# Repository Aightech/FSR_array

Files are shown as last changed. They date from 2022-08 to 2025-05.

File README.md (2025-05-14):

# FSR_array

This project implements a electronic skin using a FSR accelerometers arrays. 

The electronic board uses two multiplexers and two 16-channel ADCs to read the FSRs. The multiplexers are used to select the row or column of the FSRs array. The ADCs are used to read the FSRs values.
A teensy 4.1 is used to control the multiplexers and ADCs and to send the data to the computer.
The teensy 4.1 is connected to the computer using a USB cable or ethernet cable.
There are two modes of operation:
- **Single mode**: In this mode, you can connect a FSR array with up to 32x32 FSRs.
- **Dual mode**: In this mode, you can connect two FSR arrays with up to 16x16 FSRs each.

The sampling is around 400KHz/channel. So for a 16x16 FSR array, the sampling rate is around 400KHz/256 = 1562.5Hz.

The project contains a C++/matlab/python code demonstrating how to communicate with the teensy 4.1 and read the FSRs values.

### Submodules dependencies
#### libraries
- [built_lsl](lib/built_lsl/README.md)
- [com_client](lib/com_client/README.md)

# Building source code

To build the project run:
```bash
cd FSR_array
mkdir build && cd build
cmake .. && make
```

# Demonstration app

When the project have been built, you can run:
```bash
./FSR_array -h
```
to get the demonstration app usage.

# Example
Open the main.cpp file to get an example how to use the lib.

# Contributing
See [CONTRIBUTING.md](CONTRIBUTING.md) for details on our code of conduct, and the process for submitting pull requests to us.

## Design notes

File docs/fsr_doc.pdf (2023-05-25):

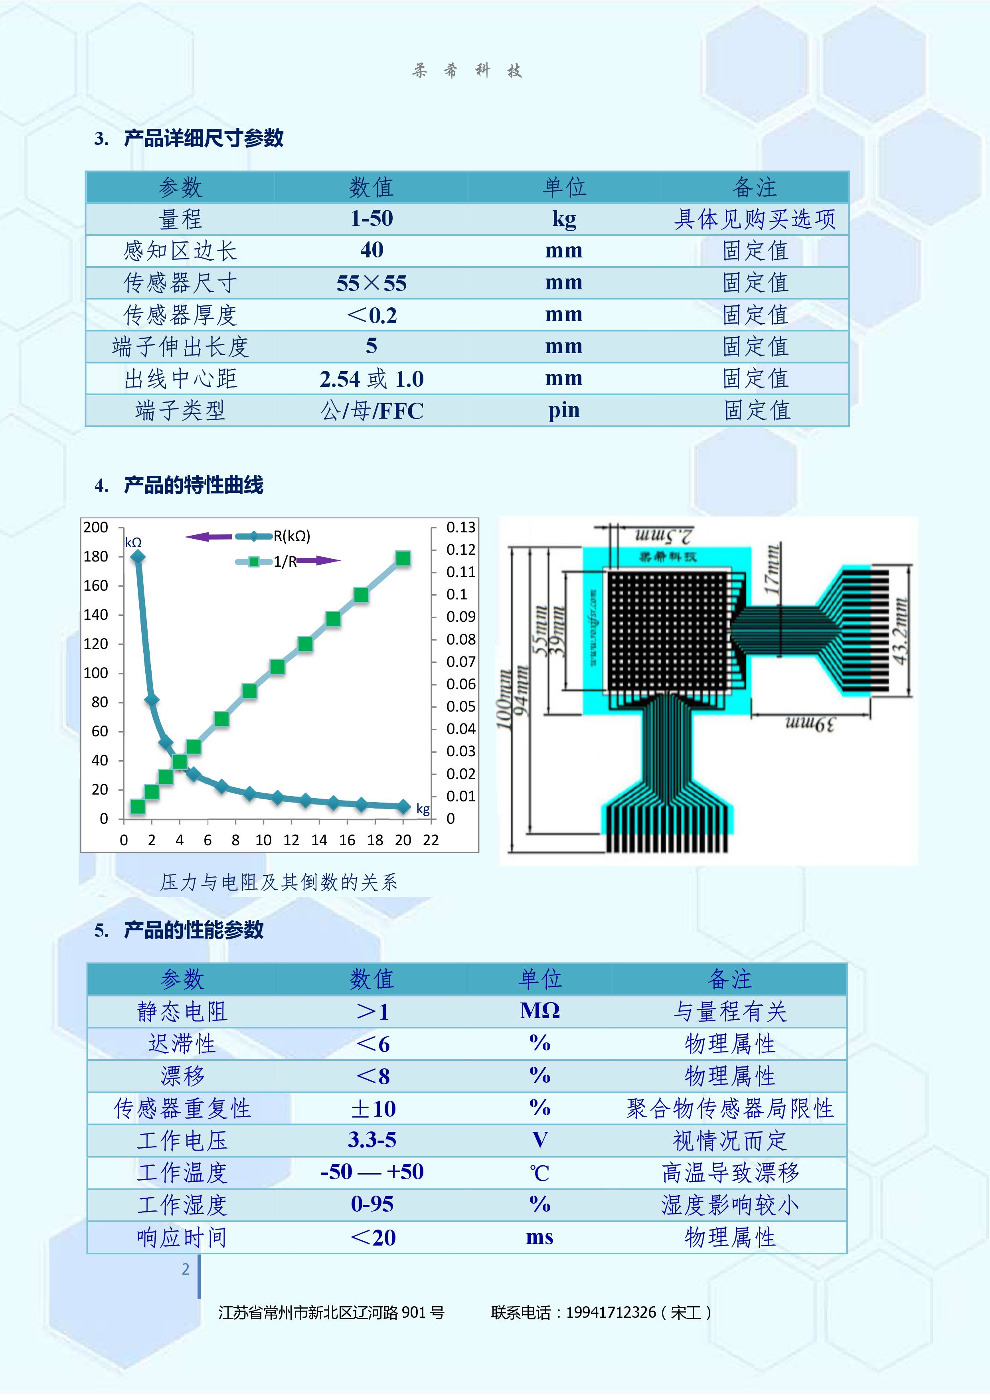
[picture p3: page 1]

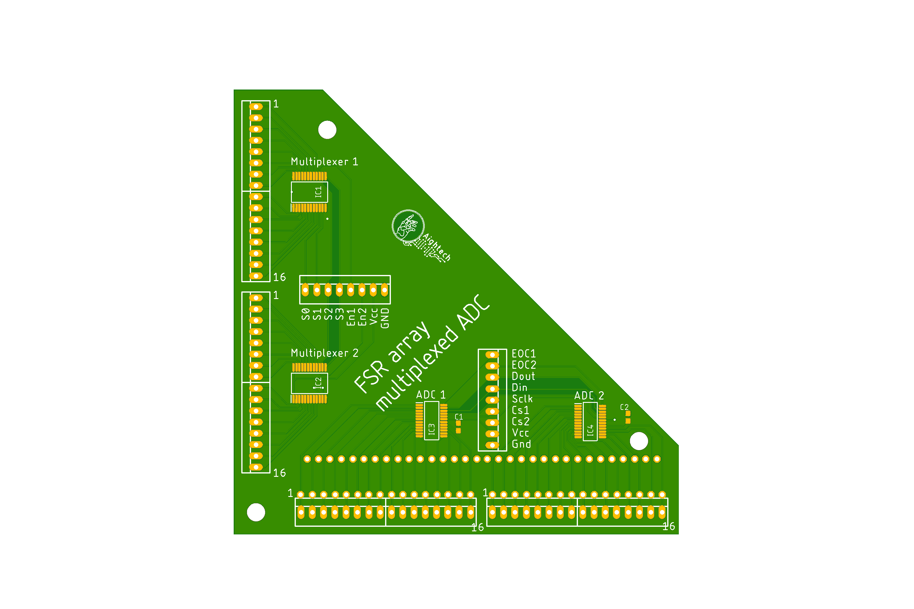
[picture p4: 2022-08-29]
docs/TOP.png

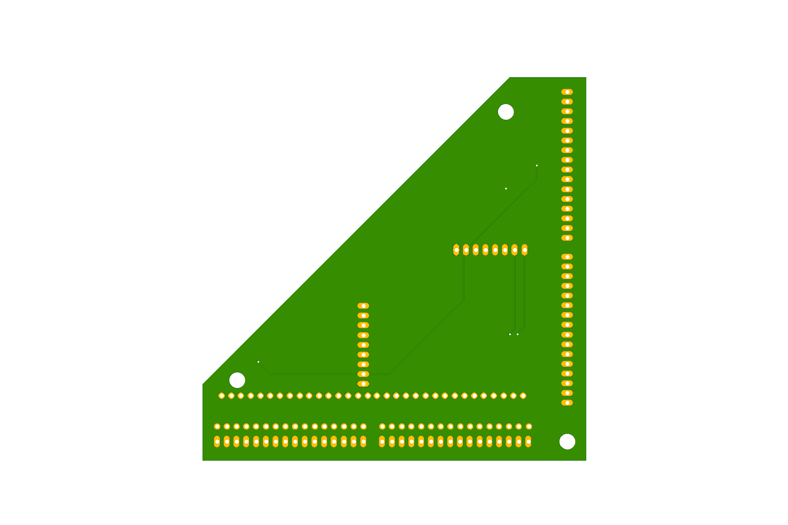
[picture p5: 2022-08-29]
docs/BOT.png

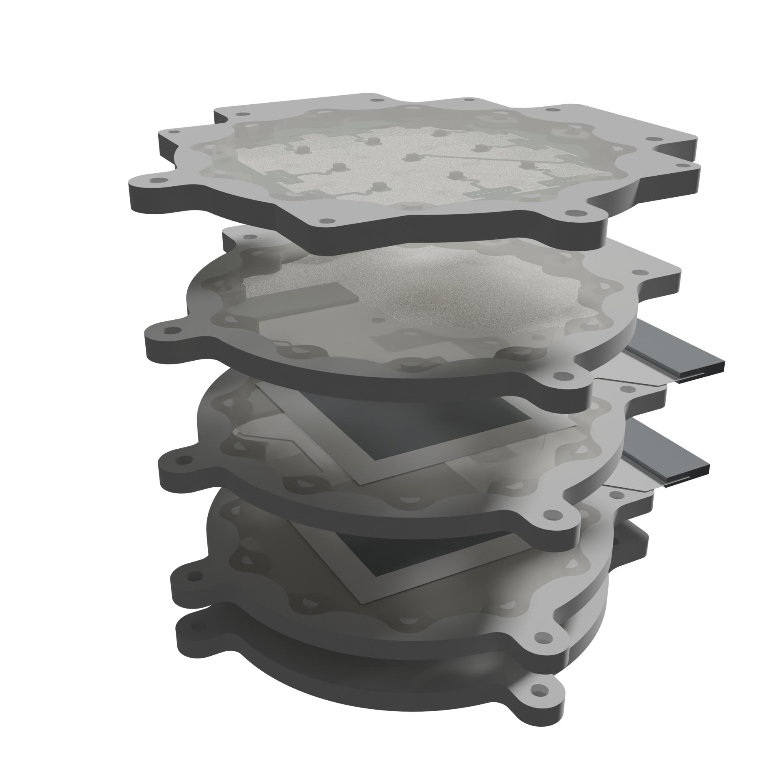
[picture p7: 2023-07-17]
models/blender/eSkin.png

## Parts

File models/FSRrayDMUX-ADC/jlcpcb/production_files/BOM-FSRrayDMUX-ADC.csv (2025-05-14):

Comment | Designator | Footprint | LCSC | Quantity
FPC-05F-16PH20 | FPC1,FPC2 | FPC-SMD_16P-P0.50_FPC-05F-16PH20 | C2856801 | 2
Conn_01x06_Pin | J1 | PinSocket_1x06_P2.54mm_Vertical |  | 1
CD74HC4067SM | MUX1 | SSOP-24_5.3x8.2mm_P0.65mm |  | 1
Conn_01x06_Pin | J4 | PinSocket_1x06_P2.54mm_Vertical |  | 1
R_Pack04 | RN4 | R_Array_Convex_4x0402 |  | 1
R_Pack04 | RN2 | R_Array_Convex_4x0402 |  | 1
R_Pack04 | RN1 | R_Array_Convex_4x0402 |  | 1
100n | C1 | C_0402_1005Metric |  | 1
R_Pack04 | RN3 | R_Array_Convex_4x0402 |  | 1
MAX11632EEGT | ADC1 | MAX11632EEGT |  | 1

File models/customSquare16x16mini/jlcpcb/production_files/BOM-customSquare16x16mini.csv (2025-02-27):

Comment | Designator | Footprint | LCSC | Quantity
FPC-05F-16PH20 | FPC1,FPC2 | FPC-SMD_16P-P0.50_FPC-05F-16PH20 | C2856801 | 2
Conn_01x16_Pin | J1 | PinSocket_1x16_P2.54mm_Vertical |  | 1
Conn_01x16_Pin | J2 | PinSocket_1x16_P2.54mm_Vertical |  | 1

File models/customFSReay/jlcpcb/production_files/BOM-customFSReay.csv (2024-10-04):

Comment | Designator | Footprint | LCSC
AFC01-S12FCA-00 | FPC1 | FPC-SMD_AFC01-S12FCA-00 | C262661
R_Pack04 | RN1 | R_Array_Convex_4x0402
R_Pack04 | RN4 | R_Array_Convex_4x0402
100n | C1 | C0603
R_Pack04 | RN2 | R_Array_Convex_4x0402
R_Pack04 | RN3 | R_Array_Convex_4x0402
CD74HC4067SM | MUX1 | SSOP-24_5.3x8.2mm_P0.65mm
MAX11632EEGT | ADC1 | MAX11632EEGT

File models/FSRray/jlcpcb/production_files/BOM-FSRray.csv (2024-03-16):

Comment | Designator | Footprint | LCSC
R_Pack04 | RN5 | R_Array_Convex_4x0402
MountingHole | H5 | MountingHole_3.2mm_M3
measuring_input4 | J2 | fcp_vertical_ULP94V0
CD74HC4067SM | MUX2 | SSOP-24_5.3x8.2mm_P0.65mm
measuring_input4 | J3 | fcp_vertical_ULP94V0
CD74HC4067SM | MUX1 | SSOP-24_5.3x8.2mm_P0.65mm
MAX11632EEGT | ADC2 | MAX11632EEGT
R_Pack04 | RN6 | R_Array_Convex_4x0402
measuring_input4 | J5 | fcp_vertical_ULP94V0
measuring_input4 | J1 | fcp_vertical_ULP94V0
R_Pack04 | RN1 | R_Array_Convex_4x0402
measuring_input4 | J4 | fcp_vertical_ULP94V0
MountingHole | H1 | MountingHole_3.2mm_M3
R_Pack04 | RN4 | R_Array_Convex_4x0402
100n | C1 | C0603
R_Pack04 | RN2 | R_Array_Convex_4x0402
teensy_left | J12 | PinSocket_1x24_P2.54mm_Vertical
R_Pack04 | RN7 | R_Array_Convex_4x0402
MAX11632EEGT | ADC1 | MAX11632EEGT
100n | C2 | C0603
R_Pack04 | RN8 | R_Array_Convex_4x0402
R_Pack04 | RN3 | R_Array_Convex_4x0402
teensy_right | J11 | PinSocket_1x24_P2.54mm_Vertical
usb_B | J17 | usbB_stewart

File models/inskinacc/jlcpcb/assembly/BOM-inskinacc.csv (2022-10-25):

Comment | Designator | Footprint | LCSC
KX134-1211 | U1 | KX134-1211
Conn_01x09_Male | J1 | PinSocket_1x09_P1.27mm_Vertical
1u | C2 | C_01005_0402Metric
100n | C1 | C_01005_0402Metric
MountingHole | H2 | MountingHole_2.2mm_M2

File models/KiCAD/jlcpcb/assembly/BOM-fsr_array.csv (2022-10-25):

Comment | Designator | Footprint | LCSC
MAX11632EEGT | ADC1 | MAX11632EEGT
MAX11632EEGT | ADC2 | MAX11632EEGT
usb_B | J17 | usbB_stewart
MountingHole | H5 | MountingHole_3.2mm_M3
100n | C2 | C0603
measuring_input2 | J6 | PinHeader_1x08_P2.54mm_Vertical
100n | C1 | C0603
scanning_ref4 | J4 | PinHeader_1x08_P2.54mm_Vertical
MountingHole | H1 | MountingHole_3.2mm_M3
teensy_left | J12 | PinSocket_1x24_P2.54mm_Vertical
CD74HC4067SM | MUX2 | SSOP-24_5.3x8.2mm_P0.65mm
com_adc | J10 | PinHeader_1x09_P2.54mm_Vertical
scanning_ref1 | J1 | PinHeader_1x08_P2.54mm_Vertical
com_acc1 | J14 | PinHeader_2x05_P1.27mm_Vertical
scanning_ref3 | J3 | PinHeader_1x08_P2.54mm_Vertical
com_acc2 | J13 | PinHeader_2x05_P1.27mm_Vertical
MountingHole | H3 | MountingHole_3.2mm_M3
teensy_right | J11 | PinSocket_1x24_P2.54mm_Vertical
com_mux | J9 | PinHeader_1x08_P2.54mm_Vertical
measuring_input3 | J7 | PinHeader_1x08_P2.54mm_Vertical
measuring_input4 | J8 | PinHeader_1x08_P2.54mm_Vertical
MountingHole | H4 | MountingHole_3.2mm_M3
MountingHole | H2 | MountingHole_3.2mm_M3
com_acc4 | J16 | PinHeader_2x05_P1.27mm_Vertical
com_acc3 | J15 | PinHeader_2x05_P1.27mm_Vertical
measuring_input1 | J5 | PinHeader_1x08_P2.54mm_Vertical
CD74HC4067SM | MUX1 | SSOP-24_5.3x8.2mm_P0.65mm
scanning_ref2 | J2 | PinHeader_1x08_P2.54mm_Vertical

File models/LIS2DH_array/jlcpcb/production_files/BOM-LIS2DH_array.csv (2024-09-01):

Comment | Designator | Footprint | LCSC
LIS2DH12TR | U1,U10,U11,U12,U13,U14,U15,U16,U2,U3,U4,U5,U6,U7,U8,U9 | LGA-12_L2.0-W2.0-P0.50-BL | C110926
100n | C1,C11,C13,C15,C17,C19,C21,C23,C25,C27,C29,C3,C31,C5,C7,C9 | C_0402_1005Metric_Pad0.74x0.62mm_HandSolder | C1525
AFC01-S22FCA-00 | FPC17 | FPC-SMD_P0.5-22P_FGS-XJ-H2.0 | C262668
HC-FPC-05-09-6RLTAG | FPC1,FPC10,FPC11,FPC12,FPC13,FPC14,FPC15,FPC16,FPC2,FPC3,FPC4,FPC5,FPC6,FPC7,FPC8,FPC9 | FPC-SMD_6P-P0.50_HC-FPC-05-09-6RLTAG | C5213748
1uF | C10,C12,C14,C16,C18,C2,C20,C22,C24,C26,C28,C30,C32,C4,C6,C8 | C_0402_1005Metric_Pad0.74x0.62mm_HandSolder | C52923
SN74LVC1G32DCKR | U17,U18,U19,U20,U21,U22,U23,U24,U25,U26,U27,U28,U29,U30,U31,U32 | SOT-353_L2.1-W1.3-P0.65-LS2.3-BR | C7840

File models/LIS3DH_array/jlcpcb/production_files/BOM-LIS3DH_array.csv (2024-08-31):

Comment | Designator | Footprint | LCSC
LIS3DH | U1,U10,U11,U12,U13,U14,U15,U16,U2,U3,U4,U5,U6,U7,U8,U9 | LGA-16_3x3mm_P0.5mm_LayoutBorder3x5y | C15134
AFC01-S22FCA-00 | FPC17 | FPC-SMD_P0.5-22P_FGS-XJ-H2.0 | C262668
1u | C10,C12,C14,C16,C18,C2,C20,C22,C24,C26,C28,C30,C32,C4,C6,C8 | C_0402_1005Metric_Pad0.74x0.62mm_HandSolder | C307413
100n | C1,C11,C13,C15,C17,C19,C21,C23,C25,C27,C29,C3,C31,C5,C7,C9 | C_0402_1005Metric_Pad0.74x0.62mm_HandSolder | C41851
HC-FPC-05-09-6RLTAG | FPC1,FPC10,FPC11,FPC12,FPC13,FPC14,FPC15,FPC16,FPC2,FPC3,FPC4,FPC5,FPC6,FPC7,FPC8,FPC9 | FPC-SMD_6P-P0.50_HC-FPC-05-09-6RLTAG | C5213748
SN74LVC1G32DCKR | U17,U18,U19,U20,U21,U22,U23,U24,U25,U26,U27,U28,U29,U30,U31,U32 | SOT-353_L2.1-W1.3-P0.65-LS2.3-BR | C7840

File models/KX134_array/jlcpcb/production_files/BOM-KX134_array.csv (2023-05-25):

Comment | Designator | Footprint | LCSC
Conn_01x08_Socket | J7 | PinSocket_1x08_P1.27mm_Vertical
Conn_01x08_Socket | J1 | PinSocket_1x08_P1.27mm_Vertical
Conn_01x08_Socket | J2 | PinSocket_1x08_P1.27mm_Vertical
Conn_01x08_Socket | J8 | PinSocket_1x08_P1.27mm_Vertical
Conn_01x08_Socket | J3 | PinSocket_1x08_P1.27mm_Vertical
Conn_01x08_Socket | J9 | PinSocket_1x08_P1.27mm_Vertical
Conn_01x08_Socket | J4 | PinSocket_1x08_P1.27mm_Vertical
Conn_01x08_Socket | J5 | PinSocket_1x08_P1.27mm_Vertical
Conn_01x08_Socket | J6 | PinSocket_1x08_P1.27mm_Vertical
1u | C10 | C_01005_0402Metric
1u | C2 | C_01005_0402Metric
Conn_01x09_Socket | J10 | PinHeader_1x09_P2.54mm_Vertical
100n | C9 | C_01005_0402Metric
100n | C7 | C_01005_0402Metric
100n | C15 | C_01005_0402Metric
100n | C17 | C_01005_0402Metric
1u | C12 | C_01005_0402Metric
1u | C8 | C_01005_0402Metric
kx134 | U5 | KX134-1211
kx134 | U3 | KX134-1211
kx134 | U9 | KX134-1211
kx134 | U1 | KX134-1211
kx134 | U8 | KX134-1211
100n | C1 | C_01005_0402Metric
kx134 | U6 | KX134-1211
1u | C14 | C_01005_0402Metric
100n | C11 | C_01005_0402Metric
Conn_01x02_Socket | J12 | PinHeader_1x02_P2.54mm_Vertical
1u | C16 | C_01005_0402Metric
100n | C5 | C_01005_0402Metric
1u | C4 | C_01005_0402Metric
kx134 | U2 | KX134-1211
Conn_01x03_Socket | J11 | PinHeader_1x03_P2.54mm_Vertical
1u | C6 | C_01005_0402Metric
kx134 | U4 | KX134-1211
kx134 | U7 | KX134-1211
1u | C18 | C_01005_0402Metric
100n | C3 | C_01005_0402Metric
100n | C13 | C_01005_0402Metric

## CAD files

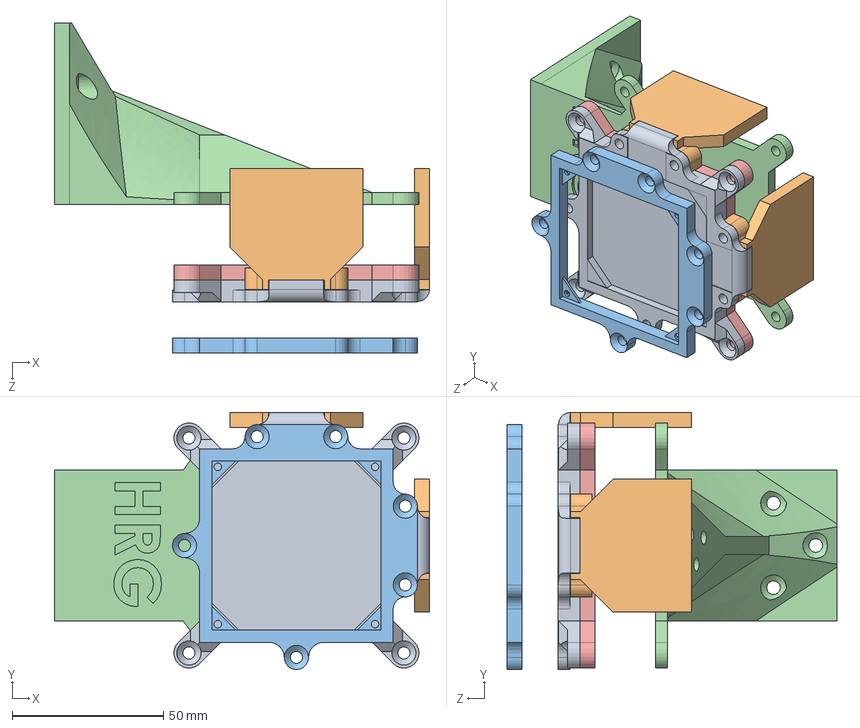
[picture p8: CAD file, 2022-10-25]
models/SW/Assem1.SLDASM
124.0 x 85.0 x 109.1 mm
FSRarray_holder_small
wire_holder x 2
siliconeTop
hman_support
force_adapter

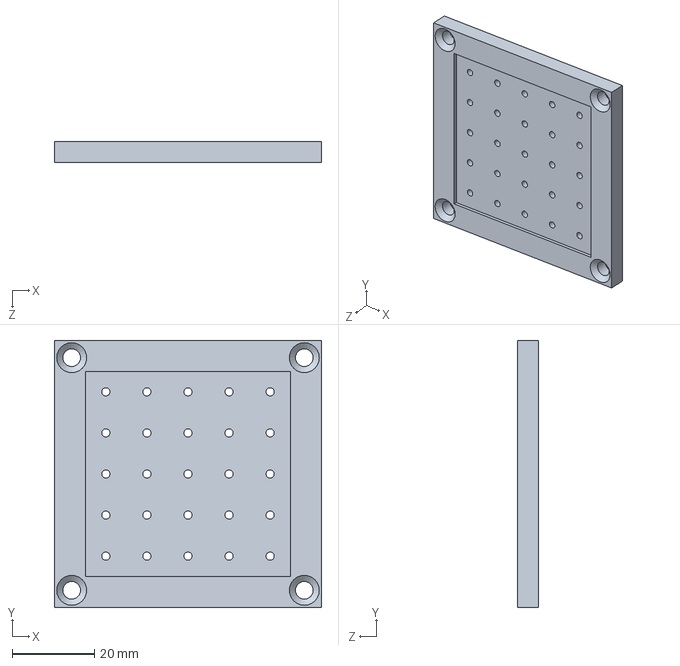
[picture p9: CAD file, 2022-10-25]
models/SW/letters/Assem2.SLDASM
65.0 x 65.0 x 5.00 mm

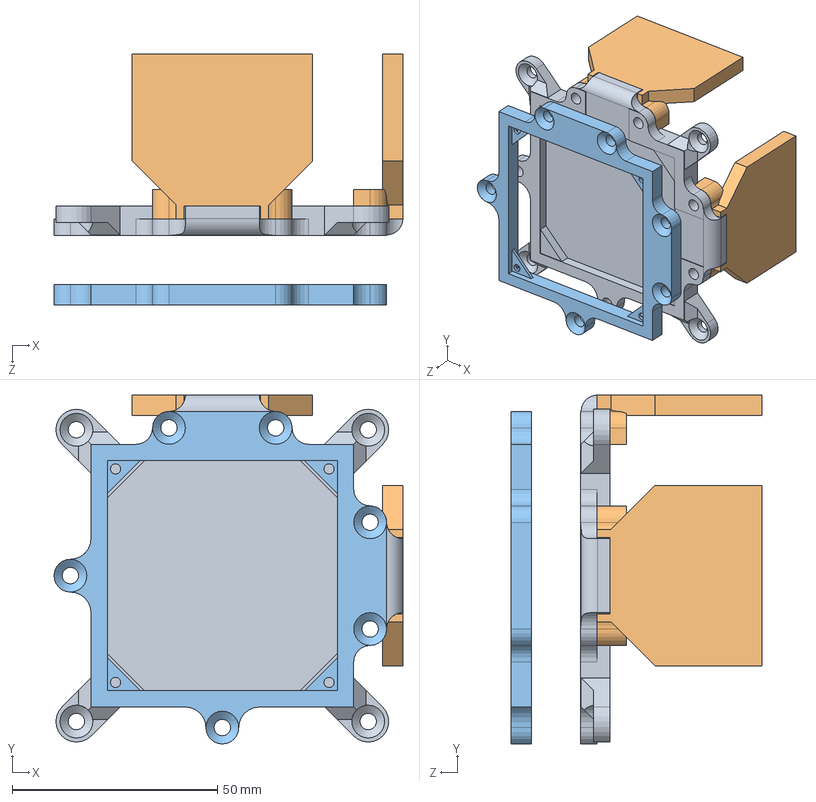
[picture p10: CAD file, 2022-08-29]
models/SW/letters/Assem1.SLDASM
85.0 x 85.0 x 61.0 mm
FSRarray_holder_small
wire_holder x 2
siliconeTop

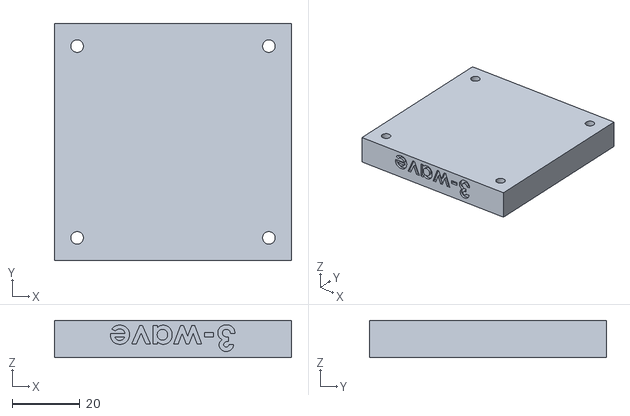
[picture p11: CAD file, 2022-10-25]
models/SW/letters/letter_T3.STL
70.0 x 70.0 x 11.0

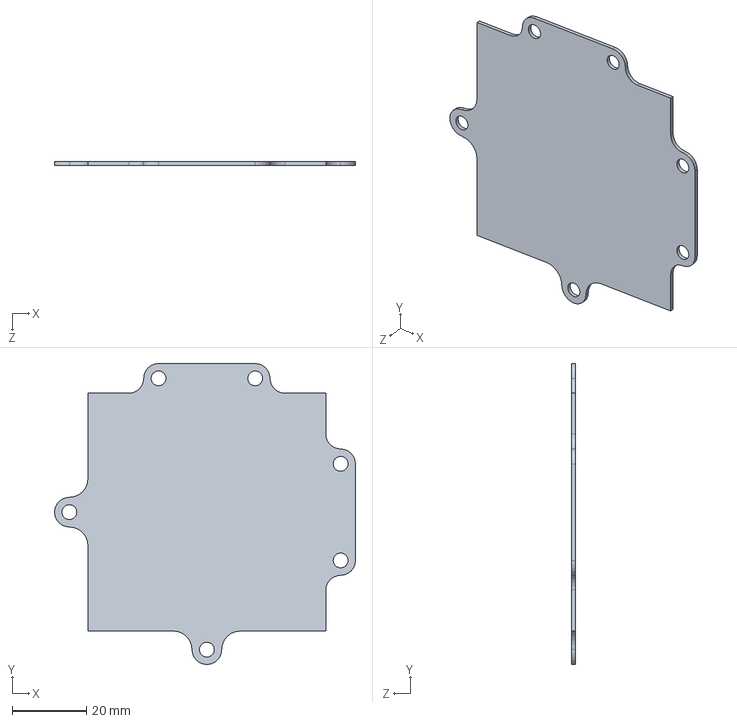
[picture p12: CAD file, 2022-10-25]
models/SW/siliconeTop.SLDPRT
81.0 x 81.0 x 1.00 mm

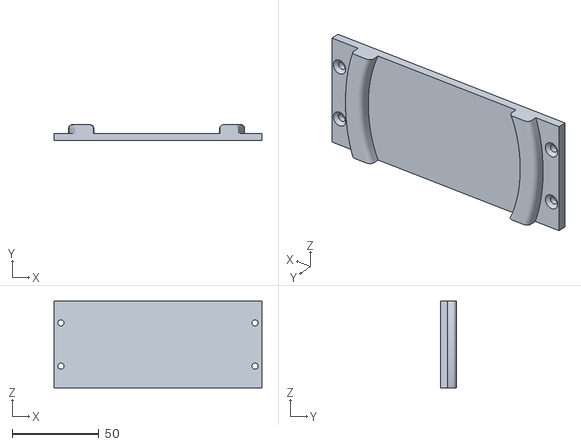
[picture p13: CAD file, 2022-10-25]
models/SW/letters/big_letters_o2.STL
120.0 x 9.00 x 50.0

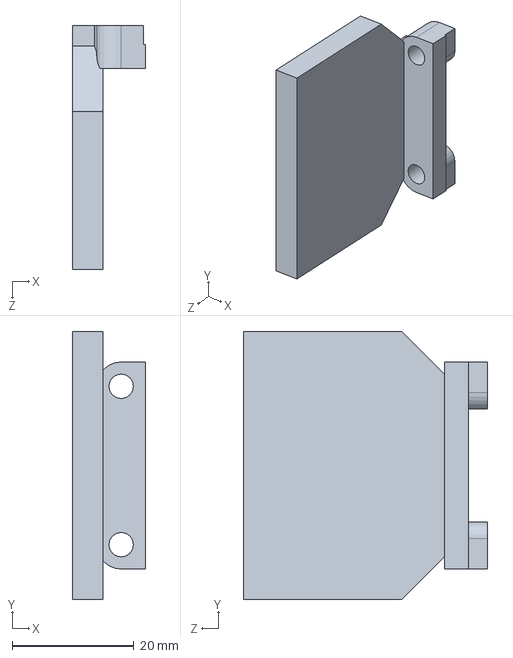
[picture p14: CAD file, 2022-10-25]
models/SW/wire_holder.SLDPRT
12.0 x 44.0 x 40.1 mm

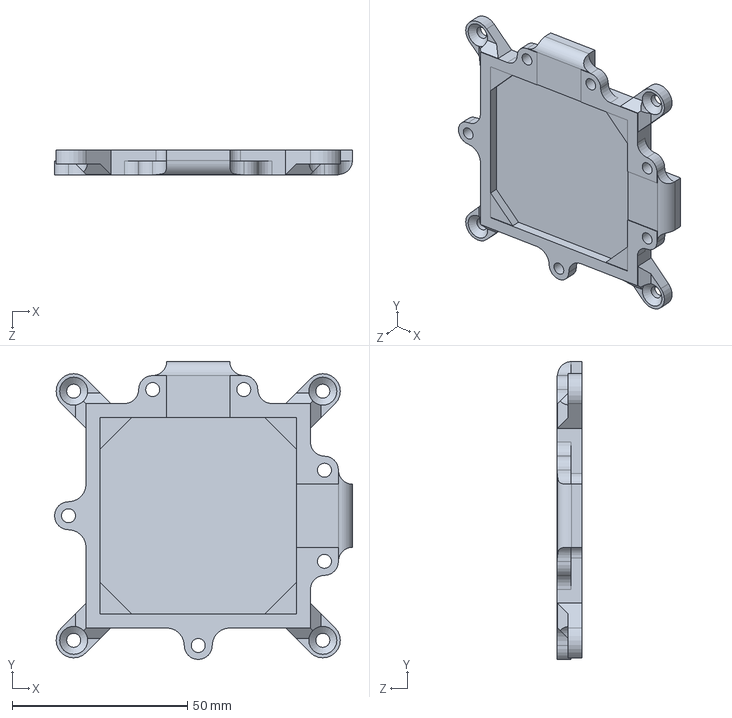
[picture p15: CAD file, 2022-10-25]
models/SW/FSRarray_holder_small.SLDPRT
85.0 x 85.0 x 7.20 mm

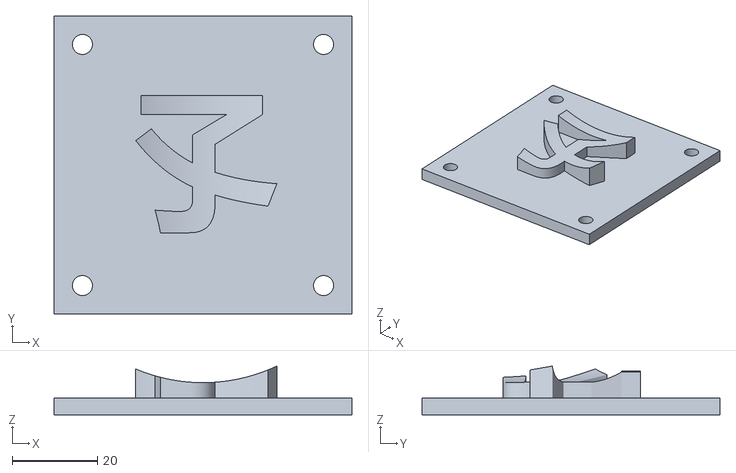
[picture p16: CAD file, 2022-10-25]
models/SW/letters/letter_JUEhard1.STL
70.0 x 70.0 x 11.5

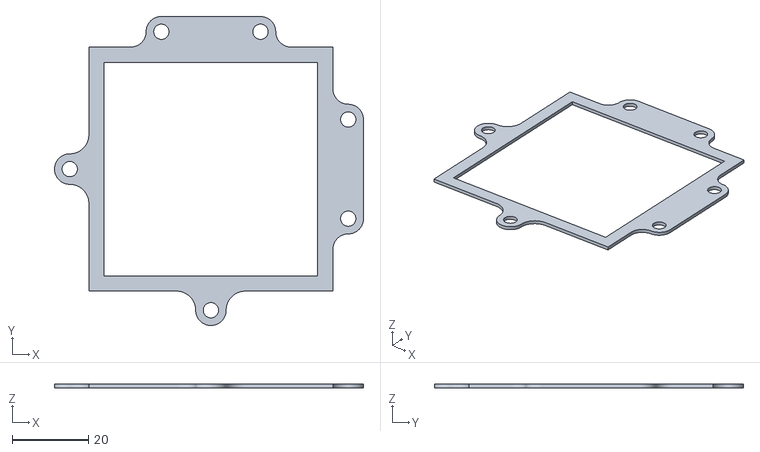
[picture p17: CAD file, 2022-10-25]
models/SW/siliconeTop_small.STL
81.0 x 81.0 x 1.00

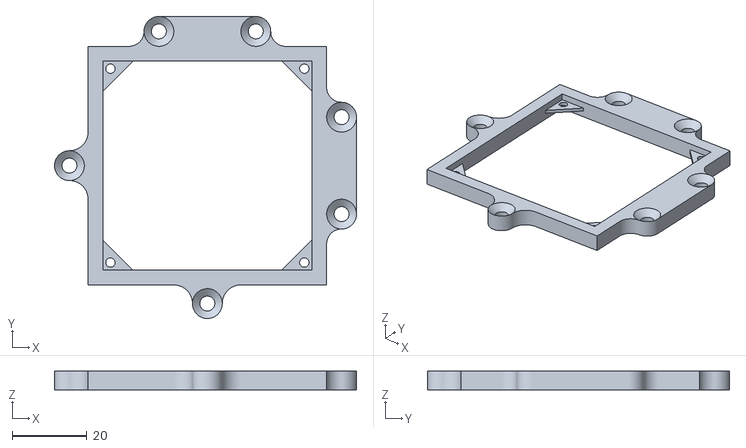
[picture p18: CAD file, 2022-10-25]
models/SW/siliconeTop_Default.STL
81.0 x 81.0 x 5.00

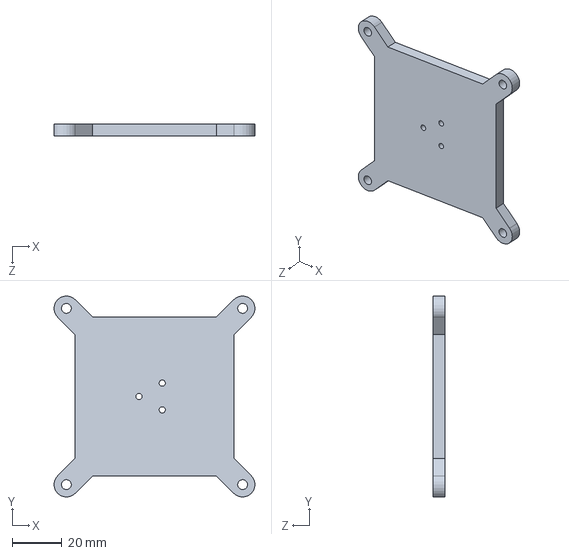
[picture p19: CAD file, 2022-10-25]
models/SW/force_adapter.SLDPRT
81.1 x 81.1 x 5.00 mm

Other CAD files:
models/SW/Assem2.SLDASM
models/SW/letters/letter_JUE2.STL
models/SW/letters/letter_H1.STL
models/SW/letters/big_letters_c1.STL
models/SW/siliconeTop_bot.STL
models/SW/letters/letter_P3.STL
models/SW/dumper.SLDPRT
models/SW/force_adapter.STL
models/SW/hman_support.SLDPRT
models/SW/hman_support.STL
models/SW/letters/FSRarray_holder_small.SLDPRT
models/SW/letters/FSRarray_holder_small.STL
models/SW/letters/big_letters.SLDPRT
models/SW/letters/big_letters_c2.STL
models/SW/letters/big_letters_c3.STL
models/SW/letters/big_letters_d1.STL
models/SW/letters/big_letters_d2.STL
models/SW/letters/big_letters_d3.STL
models/SW/letters/big_letters_o1.STL
models/SW/letters/big_letters_o3.STL
models/SW/letters/big_letters_q1.STL
models/SW/letters/big_letters_q2.STL
models/SW/letters/big_letters_q3.STL
models/SW/letters/letter.SLDPRT
models/SW/letters/letter_A1.STL
models/SW/letters/letter_A2.STL
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

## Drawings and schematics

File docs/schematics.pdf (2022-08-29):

Sheet: ABCDE | 1 | 2 | 3 | 4 | 5 | 6 | 7 | 8 | ABCDE 1 | 2 | 3 | 4 | 5 | 6 | 7 | 8

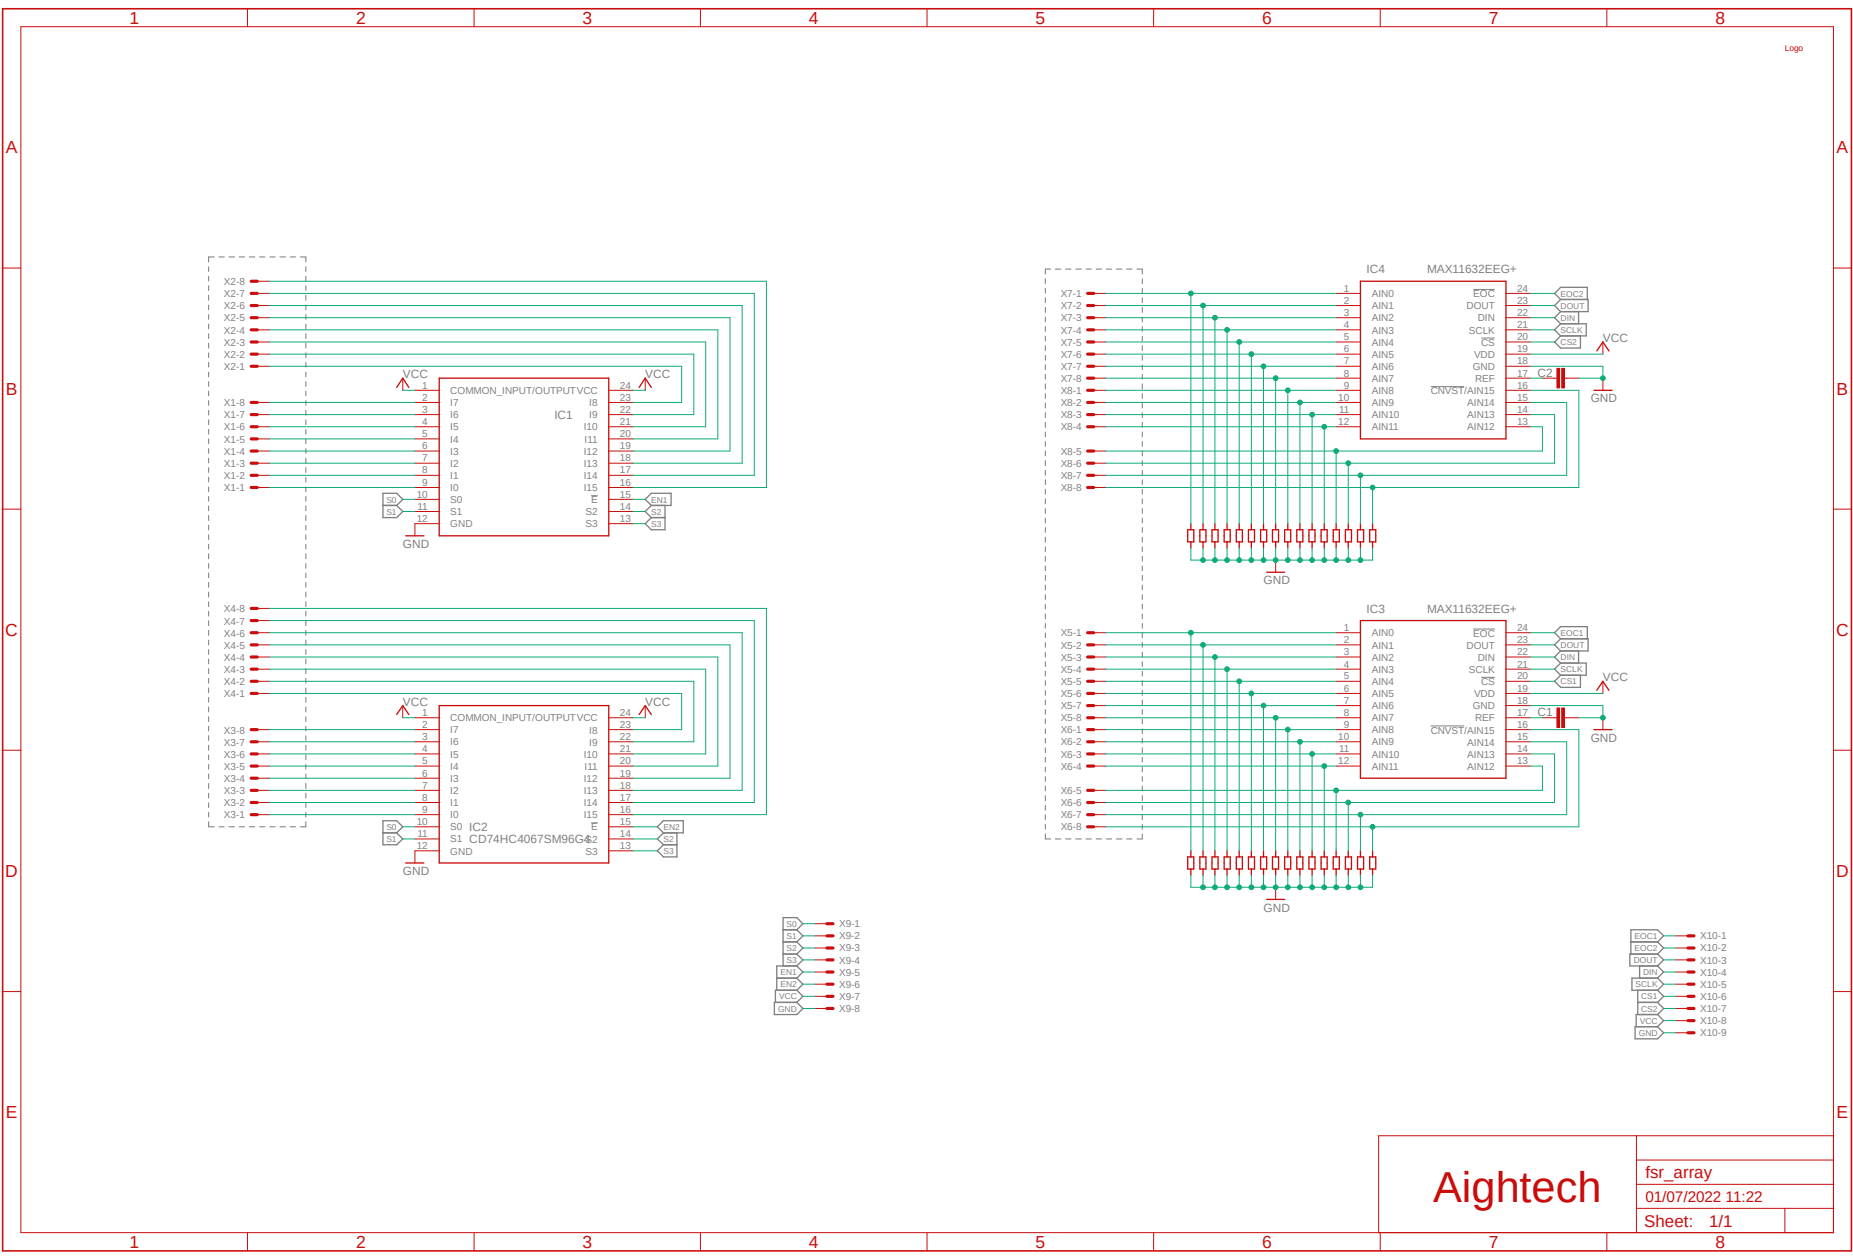
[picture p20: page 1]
MAX11632EEG+; GND; VCC; COMMON_INPUT/OUTPUT; 9 S0 10 S1 11 GND 12; AIN0; AIN1; AIN2; AIN3; AIN4; AIN5; AIN6; AIN7; AIN8; 9 AIN9 10 AIN10 11 AIN11 12; EOC; DOUT; DIN; SCLK; VDD; REF; CNVST/AIN15; AIN14; AIN13; AIN12; EOC1; EOC2; EOC2 Aightech; Logo; fsr_array 01/07/2022 11:22 1/1

S1 | GND 12 | S2

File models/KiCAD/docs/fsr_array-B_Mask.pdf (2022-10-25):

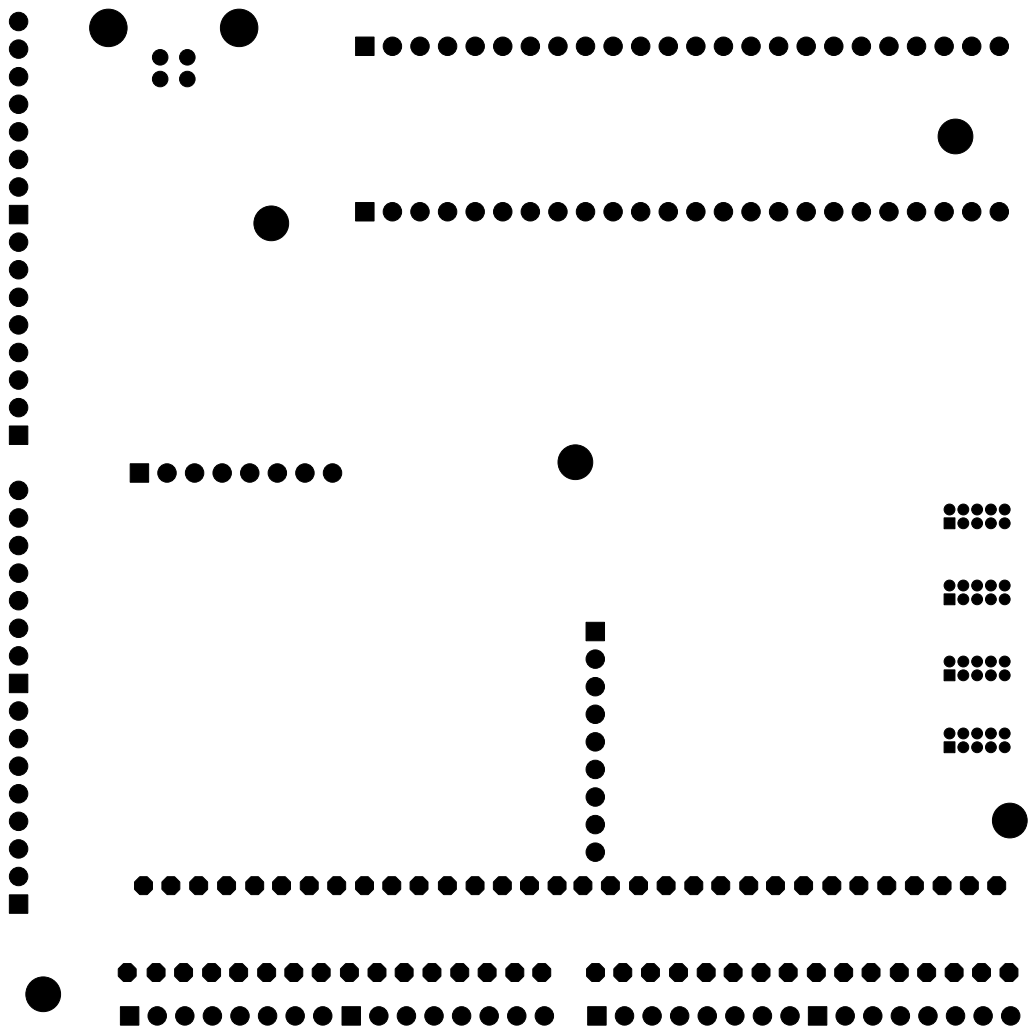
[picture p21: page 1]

File: fsr_array.kicad_pcb Sheet: Alexis Devillard - HRG - Imperial College London

Id: 1/1 Title: FSRray - Multiplexed ADCs

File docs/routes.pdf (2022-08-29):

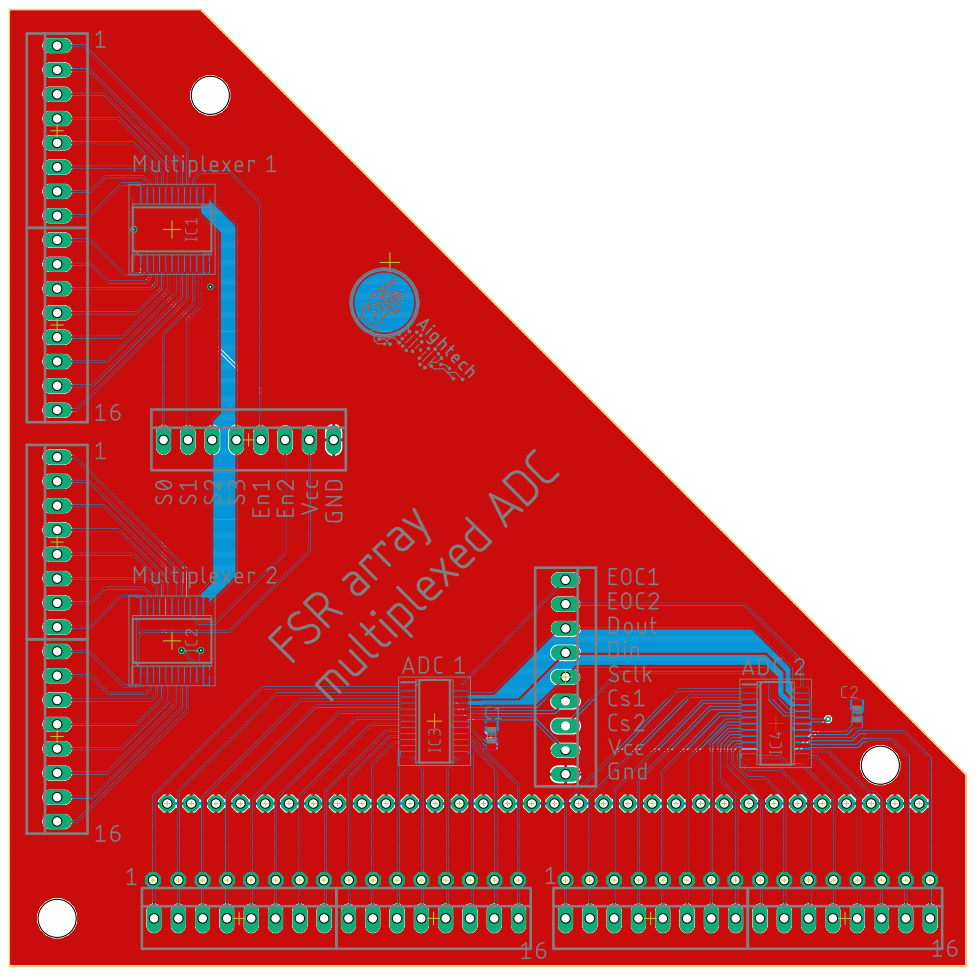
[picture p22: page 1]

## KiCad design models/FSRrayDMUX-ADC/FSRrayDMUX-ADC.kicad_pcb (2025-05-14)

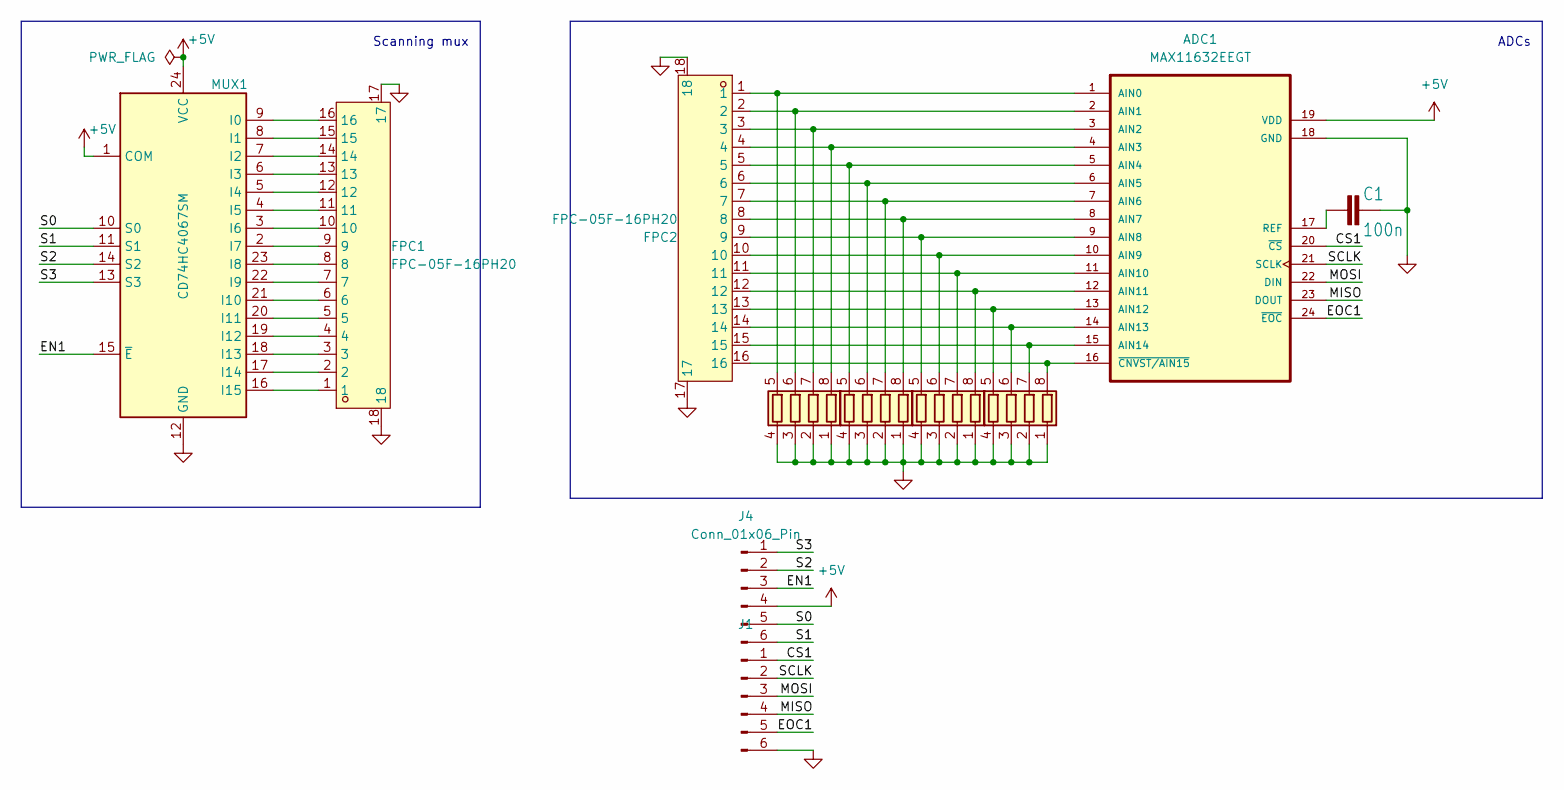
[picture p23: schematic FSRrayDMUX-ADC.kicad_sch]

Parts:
ADC1: MAX11632EEGT
C1: 100n; C_0402_1005Metric
FPC1, FPC2: FPC-05F-16PH20; FPC-SMD_16P-P0.50_FPC-05F-16PH20; LCSC Part C2856801
J1, J4: Conn_01x06_Pin; PinSocket_1x06_P2.54mm_Vertical
MUX1: CD74HC4067SM; SSOP-24_5.3x8.2mm_P0.65mm
RN1, RN2, RN3, RN4: R_Pack04; R_Array_Convex_4x0402

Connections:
+5V: ADC1.19 (VDD), J4.4, MUX1.1 (COM), MUX1.24 (VCC)
/CS1: ADC1.20 (~CS), J1.1
/EN1: J4.3, MUX1.15 (~E)
/EOC1: ADC1.24 (~EOC), J1.5
/MISO: ADC1.23 (DOUT), J1.4
/MOSI: ADC1.22 (DIN), J1.3
/S0: J4.5, MUX1.10 (S0)
/S1: J4.6, MUX1.11 (S1)
/S2: J4.2, MUX1.14 (S2)
/S3: J4.1, MUX1.13 (S3)
/SCLK: ADC1.21 (SCLK), J1.2
GND: ADC1.18 (GND), C1.2, FPC1.17, FPC1.18, FPC2.17, FPC2.18, J1.6, MUX1.12 (GND), RN1.1 (R1.1), RN1.2 (R2.1), RN1.3 (R3.1), RN1.4 (R4.1), RN2.1 (R1.1), RN2.2 (R2.1), RN2.3 (R3.1), RN2.4 (R4.1), RN3.1 (R1.1), RN3.2 (R2.1), RN3.3 (R3.1), RN3.4 (R4.1), RN4.1 (R1.1), RN4.2 (R2.1), RN4.3 (R3.1), RN4.4 (R4.1)
unnamed: ADC1.1 (AIN0), FPC2.1, RN1.5 (R4.2)
unnamed: ADC1.2 (AIN1), FPC2.2, RN1.6 (R3.2)
unnamed: ADC1.3 (AIN2), FPC2.3, RN1.7 (R2.2)
unnamed: ADC1.4 (AIN3), FPC2.4, RN1.8 (R1.2)
unnamed: ADC1.5 (AIN4), FPC2.5, RN2.5 (R4.2)
unnamed: ADC1.6 (AIN5), FPC2.6, RN2.6 (R3.2)
unnamed: ADC1.7 (AIN6), FPC2.7, RN2.7 (R2.2)
unnamed: ADC1.8 (AIN7), FPC2.8, RN2.8 (R1.2)
unnamed: ADC1.9 (AIN8), FPC2.9, RN3.5 (R4.2)
unnamed: ADC1.10 (AIN9), FPC2.10, RN3.6 (R3.2)
unnamed: ADC1.11 (AIN10), FPC2.11, RN3.7 (R2.2)
unnamed: ADC1.12 (AIN11), FPC2.12, RN3.8 (R1.2)
unnamed: ADC1.13 (AIN12), FPC2.13, RN4.5 (R4.2)
unnamed: ADC1.14 (AIN13), FPC2.14, RN4.6 (R3.2)
unnamed: ADC1.15 (AIN14), FPC2.15, RN4.7 (R2.2)
unnamed: ADC1.17 (REF), C1.1
unnamed: ADC1.16 (~CNVST/AIN15), FPC2.16, RN4.8 (R1.2)
unnamed: FPC1.16, MUX1.9 (I0)
unnamed: FPC1.15, MUX1.8 (I1)
unnamed: FPC1.14, MUX1.7 (I2)
unnamed: FPC1.13, MUX1.6 (I3)
unnamed: FPC1.12, MUX1.5 (I4)
unnamed: FPC1.11, MUX1.4 (I5)
unnamed: FPC1.10, MUX1.3 (I6)
unnamed: FPC1.9, MUX1.2 (I7)
unnamed: FPC1.8, MUX1.23 (I8)
unnamed: FPC1.7, MUX1.22 (I9)
unnamed: FPC1.6, MUX1.21 (I10)
unnamed: FPC1.5, MUX1.20 (I11)
unnamed: FPC1.4, MUX1.19 (I12)
unnamed: FPC1.3, MUX1.18 (I13)
unnamed: FPC1.2, MUX1.17 (I14)
unnamed: FPC1.1, MUX1.16 (I15)

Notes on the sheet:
ADCs
Scanning mux

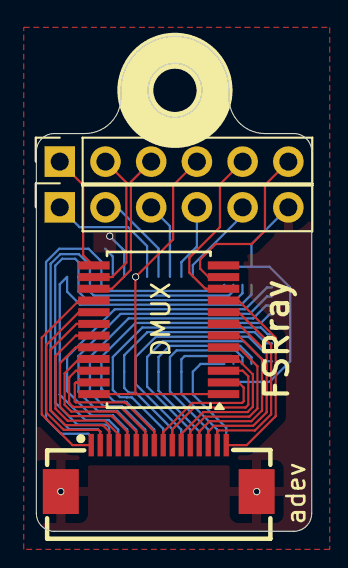
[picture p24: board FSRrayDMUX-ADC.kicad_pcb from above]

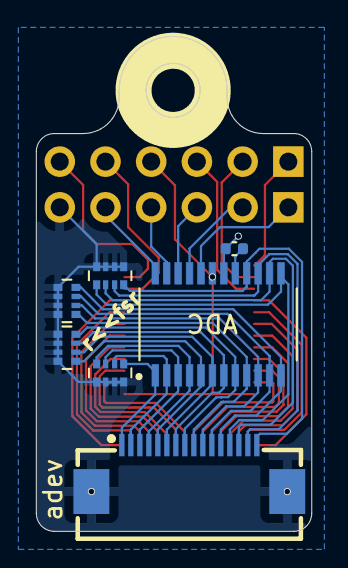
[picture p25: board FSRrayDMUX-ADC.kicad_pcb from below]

Board: 4 copper layers, 15.3 x 27.5 mm, 11 parts (7 on the bottom side), 45 nets.

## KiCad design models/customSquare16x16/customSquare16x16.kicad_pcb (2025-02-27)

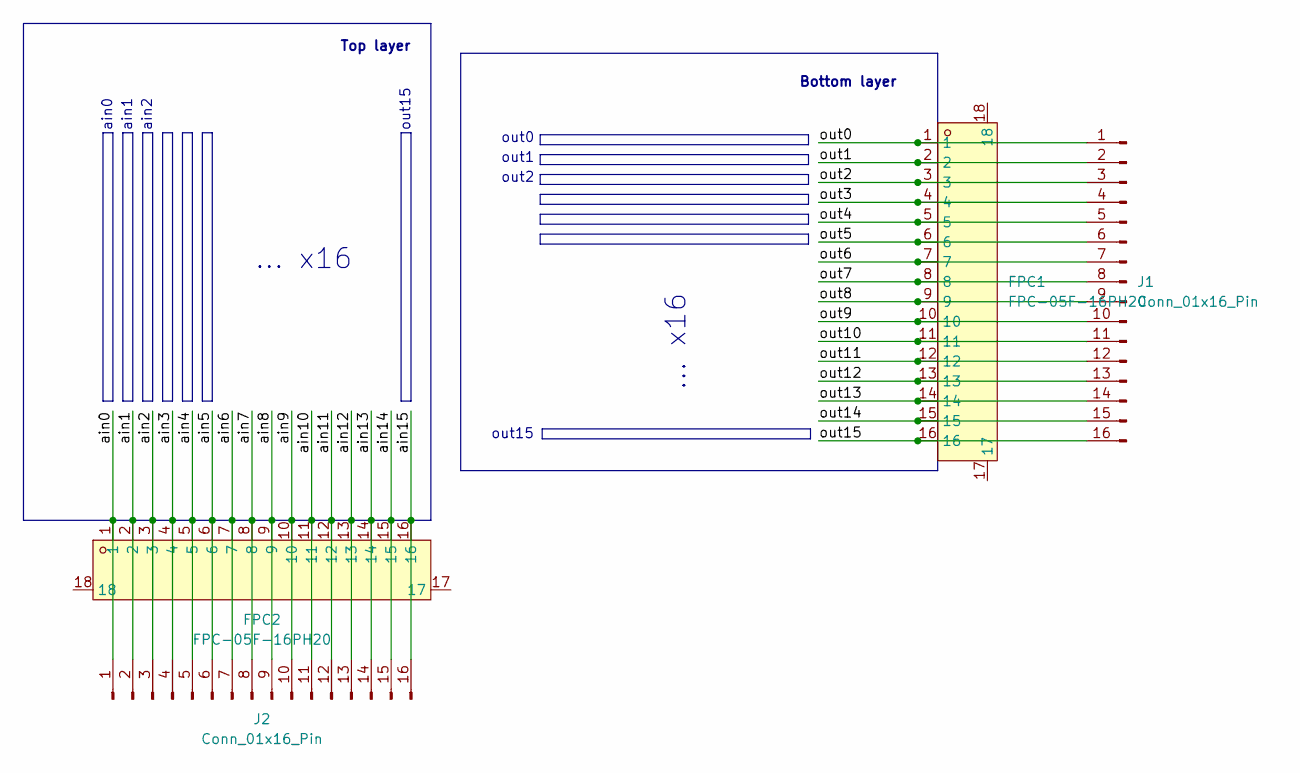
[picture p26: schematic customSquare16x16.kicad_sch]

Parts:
FPC1, FPC2: FPC-05F-16PH20; FPC-SMD_16P-P0.50_FPC-05F-16PH20; LCSC Part C2856801
J1, J2: Conn_01x16_Pin; PinSocket_1x16_P2.54mm_Vertical

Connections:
/ain0: FPC2.1, J2.1
/ain1: FPC2.2, J2.2
/ain2: FPC2.3, J2.3
/ain3: FPC2.4, J2.4
/ain4: FPC2.5, J2.5
/ain5: FPC2.6, J2.6
/ain6: FPC2.7, J2.7
/ain7: FPC2.8, J2.8
/ain8: FPC2.9, J2.9
/ain9: FPC2.10, J2.10
/ain10: FPC2.11, J2.11
/ain11: FPC2.12, J2.12
/ain12: FPC2.13, J2.13
/ain13: FPC2.14, J2.14
/ain14: FPC2.15, J2.15
/ain15: FPC2.16, J2.16
/out0: FPC1.1, J1.1
/out1: FPC1.2, J1.2
/out2: FPC1.3, J1.3
/out3: FPC1.4, J1.4
/out4: FPC1.5, J1.5
/out5: FPC1.6, J1.6
/out6: FPC1.7, J1.7
/out7: FPC1.8, J1.8
/out8: FPC1.9, J1.9
/out9: FPC1.10, J1.10
/out10: FPC1.11, J1.11
/out11: FPC1.12, J1.12
/out12: FPC1.13, J1.13
/out13: FPC1.14, J1.14
/out14: FPC1.15, J1.15
/out15: FPC1.16, J1.16

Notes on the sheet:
... x16
Bottom layer
ain0
out15
ain1
Top layer
ain2
out2
out0
out1

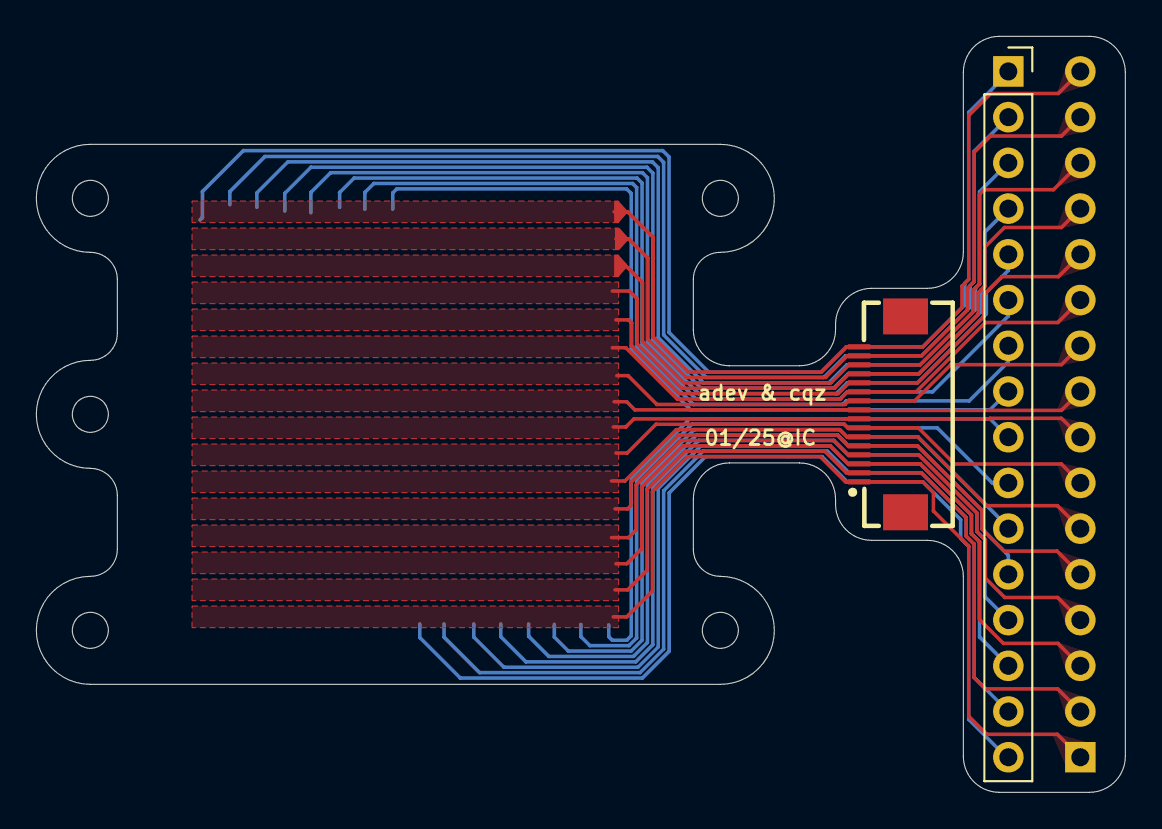
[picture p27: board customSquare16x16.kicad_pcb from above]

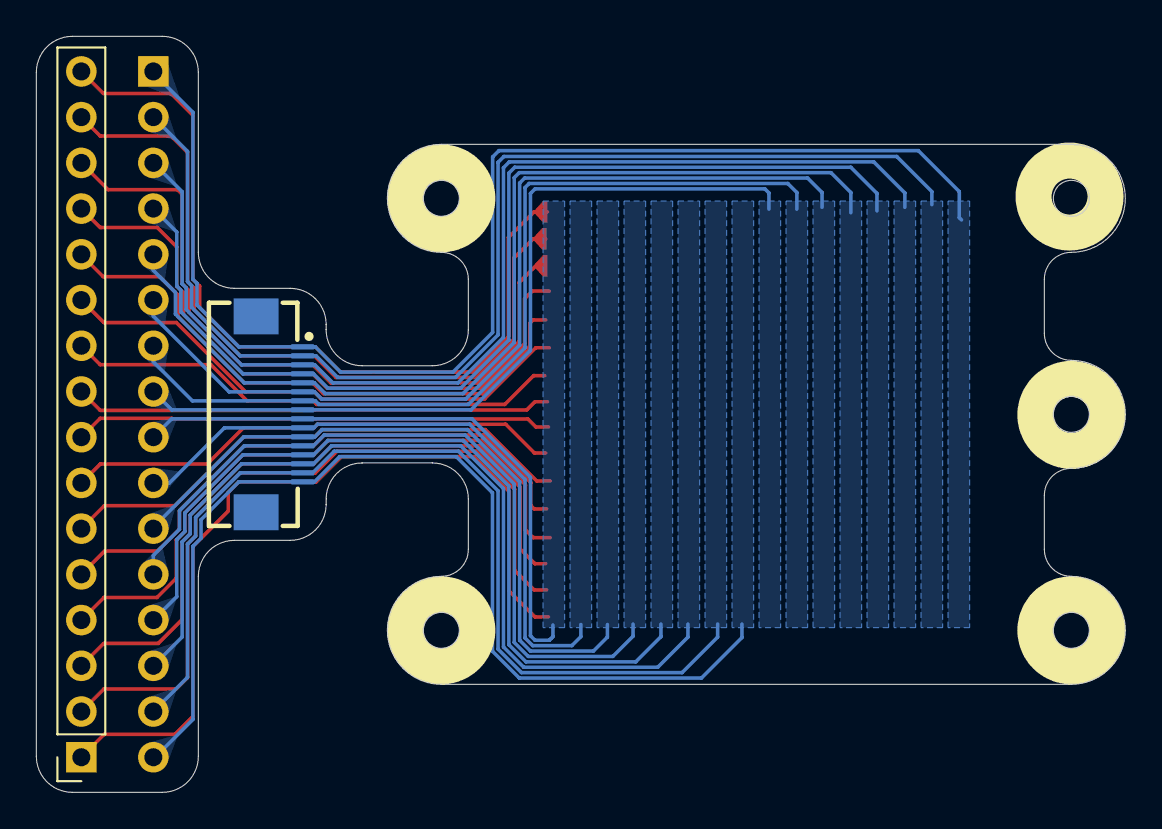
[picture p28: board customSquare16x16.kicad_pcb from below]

Board: 2 copper layers, 60.5 x 42.0 mm, 4 parts (2 on the bottom side), 32 nets.

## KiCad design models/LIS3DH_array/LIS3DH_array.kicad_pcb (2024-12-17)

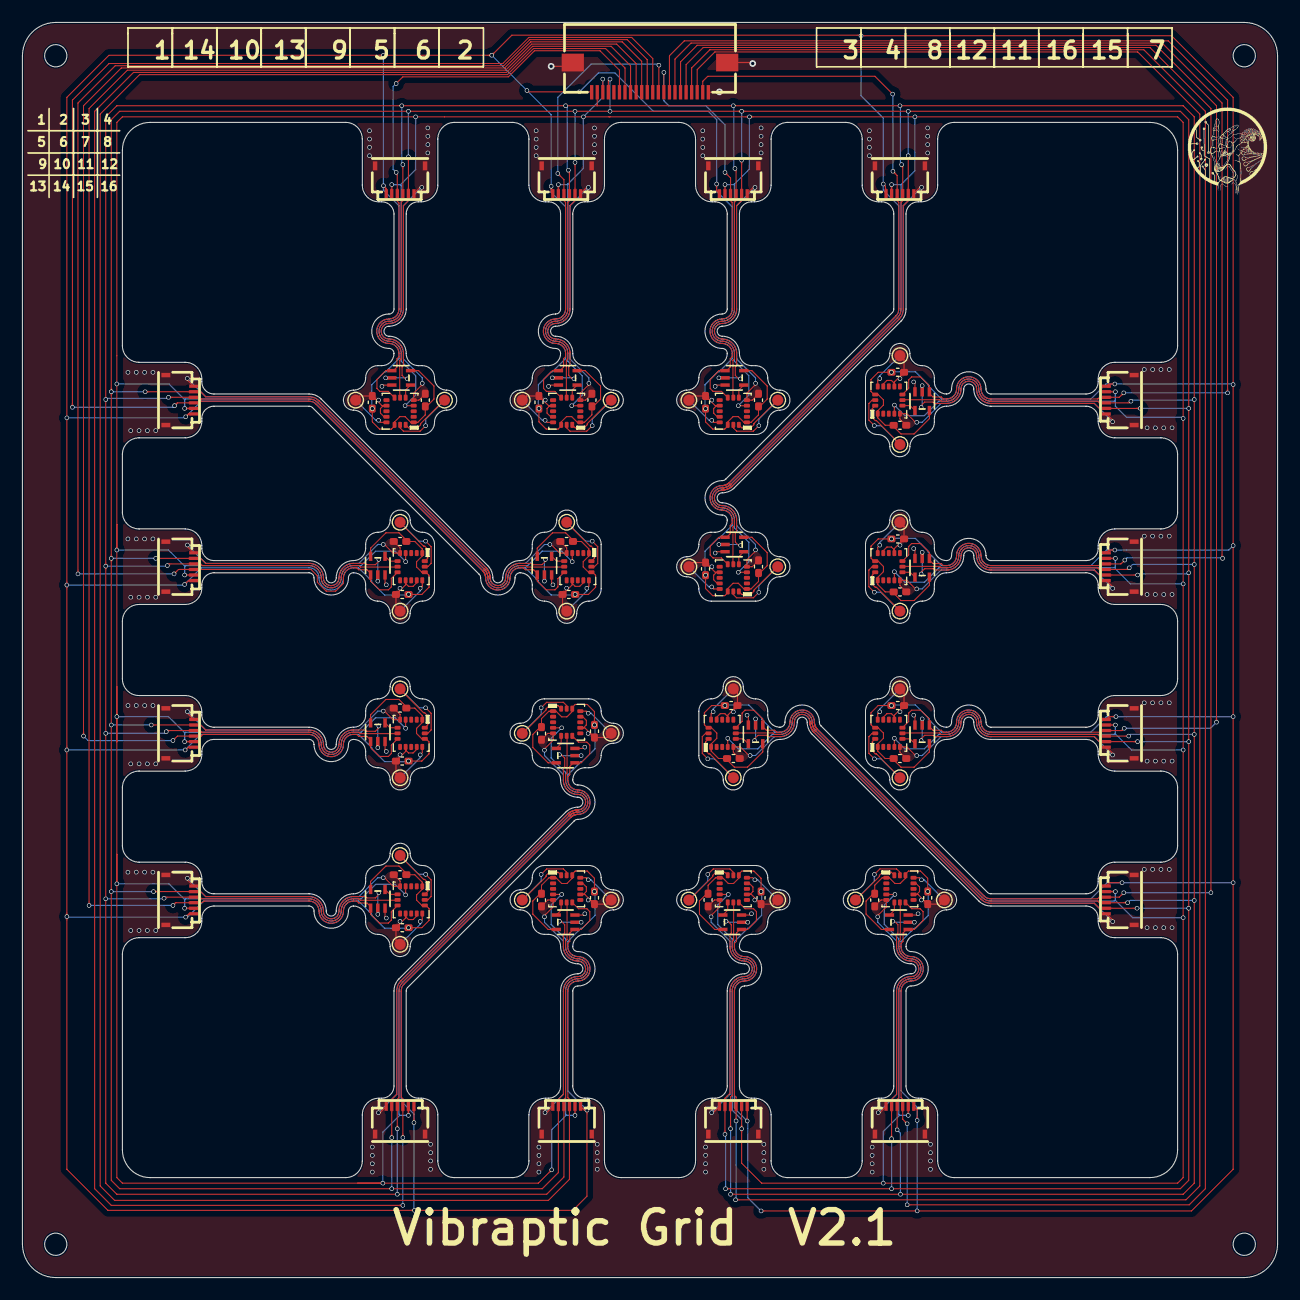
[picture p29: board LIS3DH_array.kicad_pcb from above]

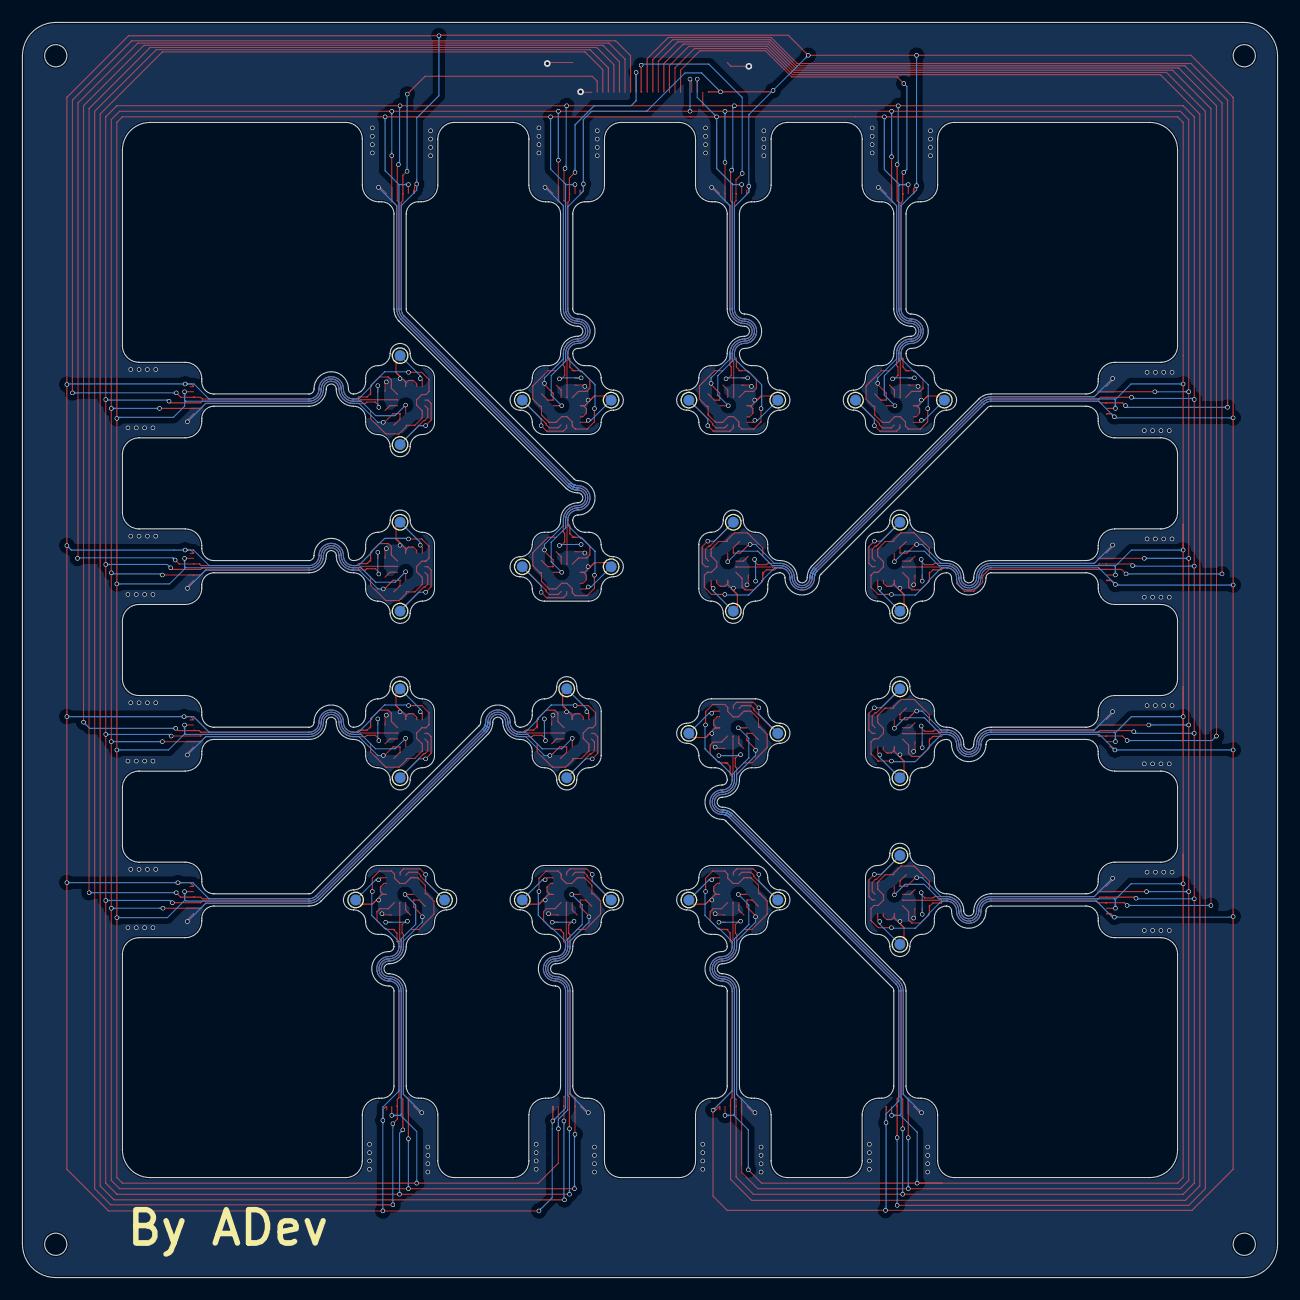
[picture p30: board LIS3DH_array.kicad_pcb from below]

Board: 2 copper layers, 113.0 x 113.0 mm, 145 parts (32 on the bottom side), 85 nets.

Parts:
C1, C3, C5, C7, C9, C11, C13, C15, C17, C19, C21, C23, C25, C27, C29, C31: 100n; C_0402_1005Metric_Pad0.74x0.62mm_HandSolder
C2, C4, C6, C8, C10, C12, C14, C16, C18, C20, C22, C24, C26, C28, C30, C32: 1u; C_0402_1005Metric_Pad0.74x0.62mm_HandSolder
FPC1, FPC2, FPC3, FPC4, FPC5, FPC6, FPC7, FPC8, FPC9, FPC10, FPC11, FPC12, FPC13, FPC14, FPC15, FPC16: HC-FPC-05-09-6RLTAG; FPC-SMD_6P-P0.50_HC-FPC-05-09-6RLTAG
FPC17: AFC01-S22FCA-00; FPC-SMD_P0.5-22P_FGS-XJ-H2.0
TP1, TP2, TP3, TP4, TP5, TP6, TP7, TP8, TP9, TP10, TP11, TP12, TP13, TP14, TP15, TP16, TP17, TP18, TP19, TP20, TP21, TP22, TP23, TP24, TP25, TP26, TP27, TP28, TP29, TP30, TP31, TP32, TP33, TP34, TP35, TP36, TP37, TP38, TP39, TP40, TP41, TP42, TP43, TP44, TP45, TP46, TP47, TP48, TP49, TP50, TP51, TP52, TP53, TP54, TP55, TP56, TP57, TP58, TP59, TP60, TP61, TP62, TP63, TP64: TestPoint; TestPoint_Pad_D1.0mm
U1, U2, U3, U4, U5, U6, U7, U8, U9, U10, U11, U12, U13, U14, U15, U16: LIS3DH; LGA-16_3x3mm_P0.5mm_LayoutBorder3x5y
U17, U18, U19, U20, U21, U22, U23, U24, U25, U26, U27, U28, U29, U30, U31, U32: SN74LVC1G32DCKR; SOT-353_L2.1-W1.3-P0.65-LS2.3-BR

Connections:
/LIS3DH_unit1/ADC1: TP1.1, U1.16 (ADC1)
/LIS3DH_unit1/ADC2: TP10.1, U1.15 (ADC2)
/LIS3DH_unit1/ADC3: TP19.1, U1.13 (ADC3)
/LIS3DH_unit2/ADC1: TP2.1, U2.16 (ADC1)
/LIS3DH_unit2/ADC2: TP11.1, U2.15 (ADC2)
/LIS3DH_unit2/ADC3: TP20.1, U2.13 (ADC3)
/LIS3DH_unit3/ADC1: TP3.1, U3.16 (ADC1)
/LIS3DH_unit3/ADC2: TP12.1, U3.15 (ADC2)
/LIS3DH_unit3/ADC3: TP21.1, U3.13 (ADC3)
/LIS3DH_unit4/ADC1: TP4.1, U4.16 (ADC1)
/LIS3DH_unit4/ADC2: TP13.1, U4.15 (ADC2)
/LIS3DH_unit4/ADC3: TP22.1, U4.13 (ADC3)
/LIS3DH_unit5/ADC1: TP5.1, U5.16 (ADC1)
/LIS3DH_unit5/ADC2: TP14.1, U5.15 (ADC2)
/LIS3DH_unit5/ADC3: TP23.1, U5.13 (ADC3)
/LIS3DH_unit6/ADC1: TP6.1, U6.16 (ADC1)
/LIS3DH_unit6/ADC2: TP15.1, U6.15 (ADC2)
/LIS3DH_unit6/ADC3: TP24.1, U6.13 (ADC3)
/LIS3DH_unit7/ADC1: TP7.1, U7.16 (ADC1)
/LIS3DH_unit7/ADC2: TP16.1, U7.15 (ADC2)
/LIS3DH_unit7/ADC3: TP25.1, U7.13 (ADC3)
/LIS3DH_unit8/ADC1: TP8.1, U8.16 (ADC1)
/LIS3DH_unit8/ADC2: TP17.1, U8.15 (ADC2)
/LIS3DH_unit8/ADC3: TP26.1, U8.13 (ADC3)
/LIS3DH_unit9/ADC1: TP9.1, U9.16 (ADC1)
/LIS3DH_unit9/ADC2: TP18.1, U9.15 (ADC2)
/LIS3DH_unit9/ADC3: TP27.1, U9.13 (ADC3)
/LIS3DH_unit10/ADC1: TP37.1, U10.16 (ADC1)
/LIS3DH_unit10/ADC2: TP38.1, U10.15 (ADC2)
/LIS3DH_unit10/ADC3: TP39.1, U10.13 (ADC3)
/LIS3DH_unit11/ADC1: TP41.1, U11.16 (ADC1)
/LIS3DH_unit11/ADC2: TP42.1, U11.15 (ADC2)
/LIS3DH_unit11/ADC3: TP43.1, U11.13 (ADC3)
/LIS3DH_unit12/ADC1: TP45.1, U12.16 (ADC1)
/LIS3DH_unit12/ADC2: TP46.1, U12.15 (ADC2)
/LIS3DH_unit12/ADC3: TP47.1, U12.13 (ADC3)
/LIS3DH_unit13/ADC1: TP49.1, U13.16 (ADC1)
/LIS3DH_unit13/ADC2: TP50.1, U13.15 (ADC2)
/LIS3DH_unit13/ADC3: TP51.1, U13.13 (ADC3)
/LIS3DH_unit14/ADC1: TP53.1, U14.16 (ADC1)
/LIS3DH_unit14/ADC2: TP54.1, U14.15 (ADC2)
/LIS3DH_unit14/ADC3: TP55.1, U14.13 (ADC3)
/LIS3DH_unit15/ADC1: TP57.1, U15.16 (ADC1)
/LIS3DH_unit15/ADC2: TP58.1, U15.15 (ADC2)
/LIS3DH_unit15/ADC3: TP59.1, U15.13 (ADC3)
/LIS3DH_unit16/ADC1: TP61.1, U16.16 (ADC1)
/LIS3DH_unit16/ADC2: TP62.1, U16.15 (ADC2)
/LIS3DH_unit16/ADC3: TP63.1, U16.13 (ADC3)
GND: C1.2, C2.2, C3.2, C4.2, C5.2, C6.2, C7.2, C8.2, C9.2, C10.2, C11.2, C12.2, C13.2, C14.2, C15.2, C16.2, C17.2, C18.2, C19.2, C20.2, C21.2, C22.2, C23.2, C24.2, C25.2, C26.2, C27.2, C28.2, C29.2, C30.2, C31.2, C32.2, FPC1.1, FPC1.7, FPC1.8, FPC2.1, FPC2.7, FPC2.8, FPC3.1, FPC3.7, FPC3.8, FPC4.1, FPC4.7, FPC4.8, FPC5.1, FPC5.7, FPC5.8, FPC6.1, FPC6.7, FPC6.8, FPC7.1, FPC7.7, FPC7.8, FPC8.1, FPC8.7, FPC8.8, FPC9.1, FPC9.7, FPC9.8, FPC10.1, FPC10.7, FPC10.8, FPC11.1, FPC11.7, FPC11.8, FPC12.1, FPC12.7, FPC12.8, FPC13.1, FPC13.7, FPC13.8, FPC14.1, FPC14.7, FPC14.8, FPC15.1, FPC15.7, FPC15.8, FPC16.1, FPC16.7, FPC16.8, FPC17.22, FPC17.23, FPC17.24, TP28.1, TP29.1, TP30.1, TP31.1, TP32.1, TP33.1, TP34.1, TP35.1, TP36.1, TP40.1, TP44.1, TP48.1, TP52.1, TP56.1, TP60.1, TP64.1, U1.5 (GND), U1.10 (RES), U1.12 (GND), U2.5 (GND), U2.10 (RES), U2.12 (GND), U3.5 (GND), U3.10 (RES), U3.12 (GND), U4.5 (GND), U4.10 (RES), U4.12 (GND), U5.5 (GND), U5.10 (RES), U5.12 (GND), U6.5 (GND), U6.10 (RES), U6.12 (GND), U7.5 (GND), U7.10 (RES), U7.12 (GND), U8.5 (GND), U8.10 (RES), U8.12 (GND), U9.5 (GND), U9.10 (RES), U9.12 (GND), U10.5 (GND), U10.10 (RES), U10.12 (GND), U11.5 (GND), U11.10 (RES), U11.12 (GND), U12.5 (GND), U12.10 (RES), U12.12 (GND), U13.5 (GND), U13.10 (RES), U13.12 (GND), U14.5 (GND), U14.10 (RES), U14.12 (GND), U15.5 (GND), U15.10 (RES), U15.12 (GND), U16.5 (GND), U16.10 (RES), U16.12 (GND), U17.3 (GND), U18.3 (GND), U19.3 (GND), U20.3 (GND), U21.3 (GND), U22.3 (GND), U23.3 (GND), U24.3 (GND), U25.3 (GND), U26.3 (GND), U27.3 (GND), U28.3 (GND), U29.3 (GND), U30.3 (GND), U31.3 (GND), U32.3 (GND)
unnamed: U1.6 (SDA/SDI/SDO), U17.4 (Y)
unnamed: U10.6 (SDA/SDI/SDO), U26.4 (Y)
unnamed: U11.6 (SDA/SDI/SDO), U27.4 (Y)
unnamed: U12.6 (SDA/SDI/SDO), U28.4 (Y)
unnamed: U13.6 (SDA/SDI/SDO), U29.4 (Y)
unnamed: U14.6 (SDA/SDI/SDO), U30.4 (Y)
unnamed: U15.6 (SDA/SDI/SDO), U31.4 (Y)
unnamed: U16.6 (SDA/SDI/SDO), U32.4 (Y)
unnamed: U2.6 (SDA/SDI/SDO), U18.4 (Y)
unnamed: U3.6 (SDA/SDI/SDO), U19.4 (Y)
unnamed: U4.6 (SDA/SDI/SDO), U20.4 (Y)
unnamed: U5.6 (SDA/SDI/SDO), U21.4 (Y)
unnamed: U6.6 (SDA/SDI/SDO), U22.4 (Y)
unnamed: U7.6 (SDA/SDI/SDO), U23.4 (Y)
unnamed: U8.6 (SDA/SDI/SDO), U24.4 (Y)
unnamed: U9.6 (SDA/SDI/SDO), U25.4 (Y)
SDI: FPC1.2, FPC2.2, FPC3.2, FPC4.2, FPC5.2, FPC6.2, FPC7.2, FPC8.2, FPC9.2, FPC10.2, FPC11.2, FPC12.2, FPC13.2, FPC14.2, FPC15.2, FPC16.2, FPC17.4, U17.2 (B), U18.2 (B), U19.2 (B), U20.2 (B), U21.2 (B), U22.2 (B), U23.2 (B), U24.2 (B), U25.2 (B), U26.2 (B), U27.2 (B), U28.2 (B), U29.2 (B), U30.2 (B), U31.2 (B), U32.2 (B)
SDO: FPC1.3, FPC2.3, FPC3.3, FPC4.3, FPC5.3, FPC6.3, FPC7.3, FPC8.3, FPC9.3, FPC10.3, FPC11.3, FPC12.3, FPC13.3, FPC14.3, FPC15.3, FPC16.3, FPC17.2, U1.7 (SDO/SA0), U2.7 (SDO/SA0), U3.7 (SDO/SA0), U4.7 (SDO/SA0), U5.7 (SDO/SA0), U6.7 (SDO/SA0), U7.7 (SDO/SA0), U8.7 (SDO/SA0), U9.7 (SDO/SA0), U10.7 (SDO/SA0), U11.7 (SDO/SA0), U12.7 (SDO/SA0), U13.7 (SDO/SA0), U14.7 (SDO/SA0), U15.7 (SDO/SA0), U16.7 (SDO/SA0)
Sclk: FPC1.5, FPC2.5, FPC3.5, FPC4.5, FPC5.5, FPC6.5, FPC7.5, FPC8.5, FPC9.5, FPC10.5, FPC11.5, FPC12.5, FPC13.5, FPC14.5, FPC15.5, FPC16.5, FPC17.3, U1.4 (SCL/SPC), U2.4 (SCL/SPC), U3.4 (SCL/SPC), U4.4 (SCL/SPC), U5.4 (SCL/SPC), U6.4 (SCL/SPC), U7.4 (SCL/SPC), U8.4 (SCL/SPC), U9.4 (SCL/SPC), U10.4 (SCL/SPC), U11.4 (SCL/SPC), U12.4 (SCL/SPC), U13.4 (SCL/SPC), U14.4 (SCL/SPC), U15.4 (SCL/SPC), U16.4 (SCL/SPC)
VDD: C1.1, C2.1, C3.1, C4.1, C5.1, C6.1, C7.1, C8.1, C9.1, C10.1, C11.1, C12.1, C13.1, C14.1, C15.1, C16.1, C17.1, C18.1, C19.1, C20.1, C21.1, C22.1, C23.1, C24.1, C25.1, C26.1, C27.1, C28.1, C29.1, C30.1, C31.1, C32.1, FPC1.6, FPC2.6, FPC3.6, FPC4.6, FPC5.6, FPC6.6, FPC7.6, FPC8.6, FPC9.6, FPC10.6, FPC11.6, FPC12.6, FPC13.6, FPC14.6, FPC15.6, FPC16.6, FPC17.1, U1.1 (VDD_IO), U1.14 (VDD), U2.1 (VDD_IO), U2.14 (VDD), U3.1 (VDD_IO), U3.14 (VDD), U4.1 (VDD_IO), U4.14 (VDD), U5.1 (VDD_IO), U5.14 (VDD), U6.1 (VDD_IO), U6.14 (VDD), U7.1 (VDD_IO), U7.14 (VDD), U8.1 (VDD_IO), U8.14 (VDD), U9.1 (VDD_IO), U9.14 (VDD), U10.1 (VDD_IO), U10.14 (VDD), U11.1 (VDD_IO), U11.14 (VDD), U12.1 (VDD_IO), U12.14 (VDD), U13.1 (VDD_IO), U13.14 (VDD), U14.1 (VDD_IO), U14.14 (VDD), U15.1 (VDD_IO), U15.14 (VDD), U16.1 (VDD_IO), U16.14 (VDD), U17.5 (VCC), U18.5 (VCC), U19.5 (VCC), U20.5 (VCC), U21.5 (VCC), U22.5 (VCC), U23.5 (VCC), U24.5 (VCC), U25.5 (VCC), U26.5 (VCC), U27.5 (VCC), U28.5 (VCC), U29.5 (VCC), U30.5 (VCC), U31.5 (VCC), U32.5 (VCC)
nCS_1: FPC1.4, FPC17.6, U1.8 (CS), U17.1 (A)
nCS_2: FPC2.4, FPC17.13, U2.8 (CS), U18.1 (A)
nCS_3: FPC3.4, FPC17.14, U3.8 (CS), U19.1 (A)
nCS_4: FPC4.4, FPC17.15, U4.8 (CS), U20.1 (A)
nCS_5: FPC5.4, FPC17.11, U5.8 (CS), U21.1 (A)
nCS_6: FPC6.4, FPC17.12, U6.8 (CS), U22.1 (A)
nCS_7: FPC7.4, FPC17.21, U7.8 (CS), U23.1 (A)
nCS_8: FPC8.4, FPC17.16, U8.8 (CS), U24.1 (A)
nCS_9: FPC9.4, FPC17.10, U9.8 (CS), U25.1 (A)
nCS_10: FPC10.4, FPC17.8, U10.8 (CS), U26.1 (A)
nCS_11: FPC11.4, FPC17.18, U11.8 (CS), U27.1 (A)
nCS_12: FPC12.4, FPC17.17, U12.8 (CS), U28.1 (A)
nCS_13: FPC13.4, FPC17.9, U13.8 (CS), U29.1 (A)
nCS_14: FPC14.4, FPC17.7, U14.8 (CS), U30.1 (A)
nCS_15: FPC15.4, FPC17.20, U15.8 (CS), U31.1 (A)
nCS_16: FPC16.4, FPC17.19, U16.8 (CS), U32.1 (A)

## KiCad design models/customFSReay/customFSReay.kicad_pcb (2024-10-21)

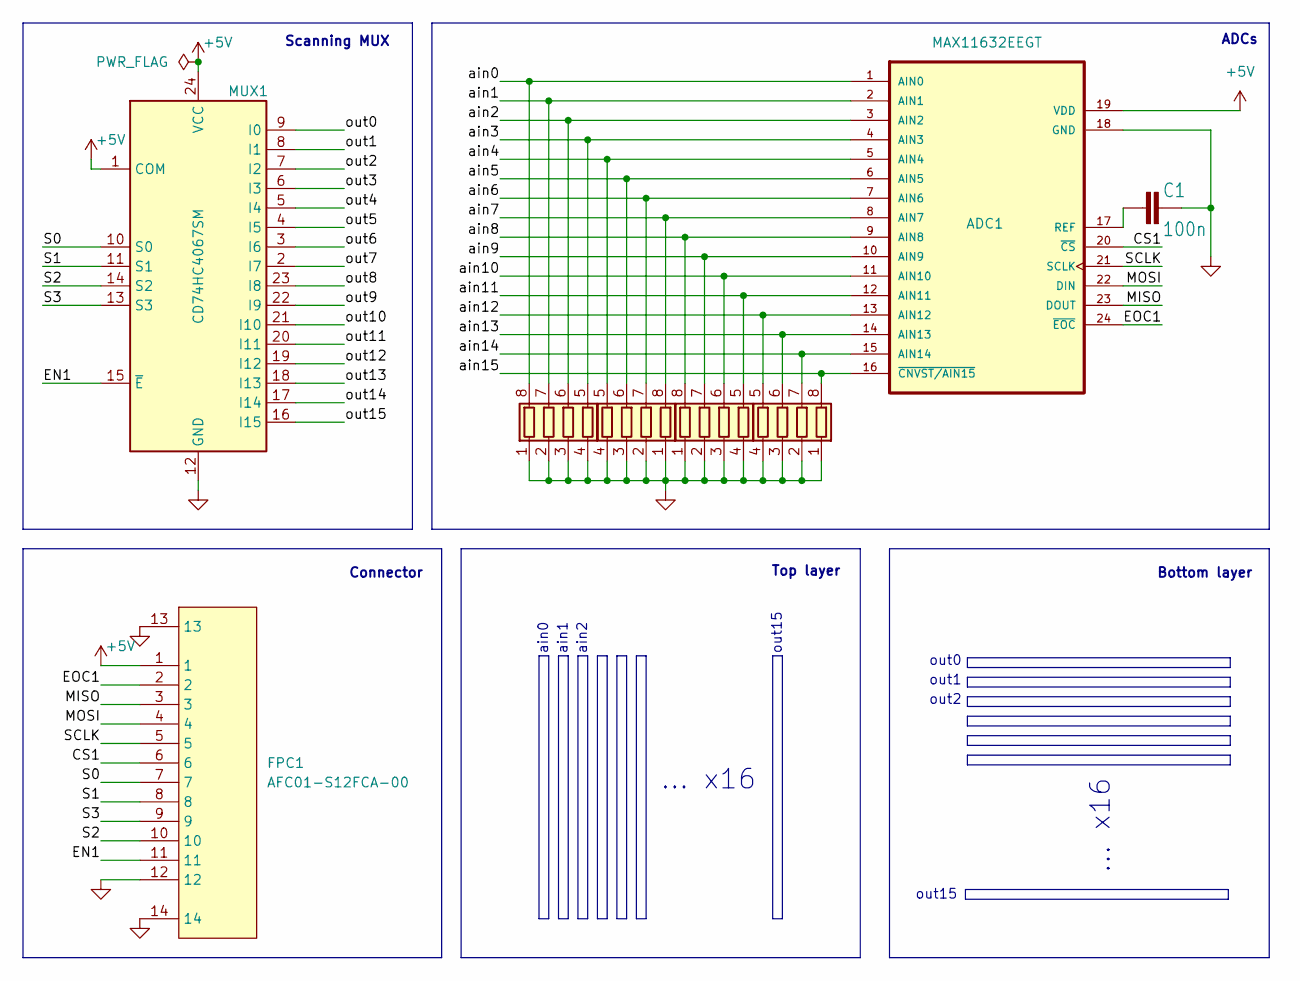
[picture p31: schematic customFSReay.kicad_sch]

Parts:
ADC1: MAX11632EEGT
C1: 100n; C0603
FPC1: AFC01-S12FCA-00; FPC-SMD_AFC01-S12FCA-00; LCSC Part C262661
MUX1: CD74HC4067SM; SSOP-24_5.3x8.2mm_P0.65mm
RN1, RN2, RN3, RN4: R_Pack04; R_Array_Convex_4x0402

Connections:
+5V: ADC1.19 (VDD), FPC1.1, MUX1.1 (COM), MUX1.24 (VCC)
/CS1: ADC1.20 (~CS), FPC1.6
/EN1: FPC1.11, MUX1.15 (~E)
/EOC1: ADC1.24 (~EOC), FPC1.2
/MISO: ADC1.23 (DOUT), FPC1.3
/MOSI: ADC1.22 (DIN), FPC1.4
/S0: FPC1.7, MUX1.10 (S0)
/S1: FPC1.8, MUX1.11 (S1)
/S2: FPC1.10, MUX1.14 (S2)
/S3: FPC1.9, MUX1.13 (S3)
/SCLK: ADC1.21 (SCLK), FPC1.5
/ain0: ADC1.1 (AIN0), RN1.8 (R1.2)
/ain1: ADC1.2 (AIN1), RN1.7 (R2.2)
/ain2: ADC1.3 (AIN2), RN1.6 (R3.2)
/ain3: ADC1.4 (AIN3), RN1.5 (R4.2)
/ain4: ADC1.5 (AIN4), RN2.5 (R4.2)
/ain5: ADC1.6 (AIN5), RN2.6 (R3.2)
/ain6: ADC1.7 (AIN6), RN2.7 (R2.2)
/ain7: ADC1.8 (AIN7), RN2.8 (R1.2)
/ain8: ADC1.9 (AIN8), RN3.8 (R1.2)
/ain9: ADC1.10 (AIN9), RN3.7 (R2.2)
/ain10: ADC1.11 (AIN10), RN3.6 (R3.2)
/ain11: ADC1.12 (AIN11), RN3.5 (R4.2)
/ain12: ADC1.13 (AIN12), RN4.5 (R4.2)
/ain13: ADC1.14 (AIN13), RN4.6 (R3.2)
/ain14: ADC1.15 (AIN14), RN4.7 (R2.2)
/ain15: ADC1.16 (~CNVST/AIN15), RN4.8 (R1.2)
/out0: MUX1.9 (I0)
/out1: MUX1.8 (I1)
/out2: MUX1.7 (I2)
/out3: MUX1.6 (I3)
/out4: MUX1.5 (I4)
/out5: MUX1.4 (I5)
/out6: MUX1.3 (I6)
/out7: MUX1.2 (I7)
/out8: MUX1.23 (I8)
/out9: MUX1.22 (I9)
/out10: MUX1.21 (I10)
/out11: MUX1.20 (I11)
/out12: MUX1.19 (I12)
/out13: MUX1.18 (I13)
/out14: MUX1.17 (I14)
/out15: MUX1.16 (I15)
GND: ADC1.18 (GND), C1.2, FPC1.12, FPC1.13, FPC1.14, MUX1.12 (GND), RN1.1 (R1.1), RN1.2 (R2.1), RN1.3 (R3.1), RN1.4 (R4.1), RN2.1 (R1.1), RN2.2 (R2.1), RN2.3 (R3.1), RN2.4 (R4.1), RN3.1 (R1.1), RN3.2 (R2.1), RN3.3 (R3.1), RN3.4 (R4.1), RN4.1 (R1.1), RN4.2 (R2.1), RN4.3 (R3.1), RN4.4 (R4.1)
unnamed: ADC1.17 (REF), C1.1

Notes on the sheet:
... x16
Bottom layer
ain0
out15
ain1
ADCs
Top layer
ain2
out2
out0
Scanning MUX
out1
Connector

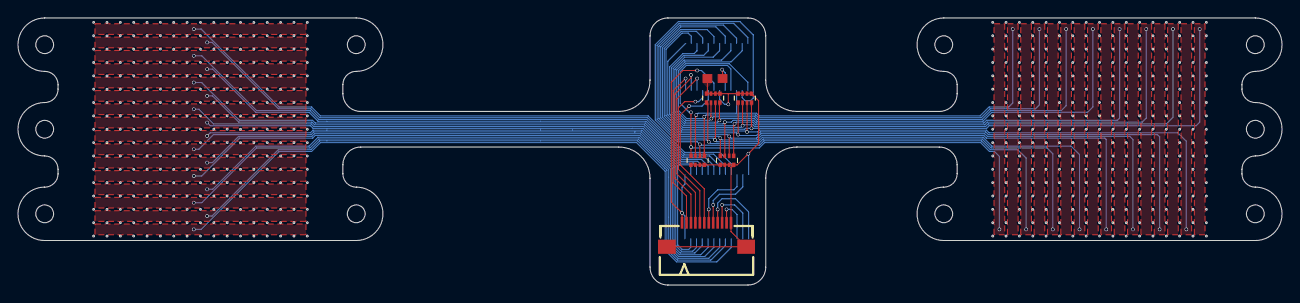
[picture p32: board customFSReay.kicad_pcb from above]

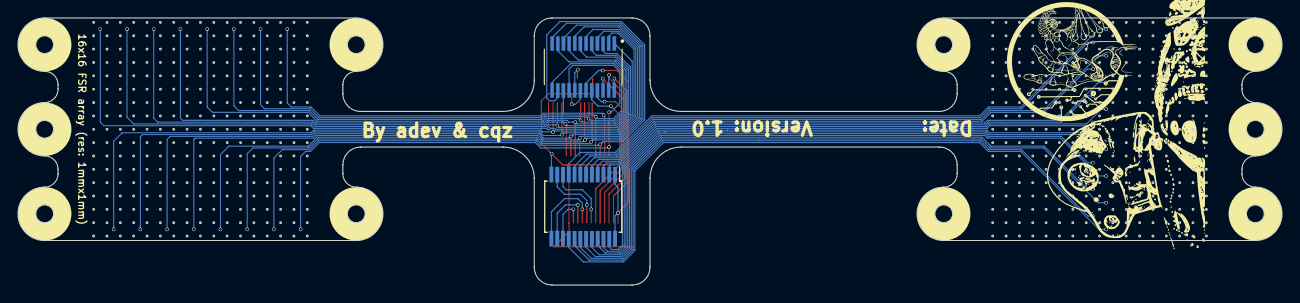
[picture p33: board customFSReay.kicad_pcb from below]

Board: 2 copper layers, 142.0 x 30.0 mm, 8 parts (2 on the bottom side), 29 nets.

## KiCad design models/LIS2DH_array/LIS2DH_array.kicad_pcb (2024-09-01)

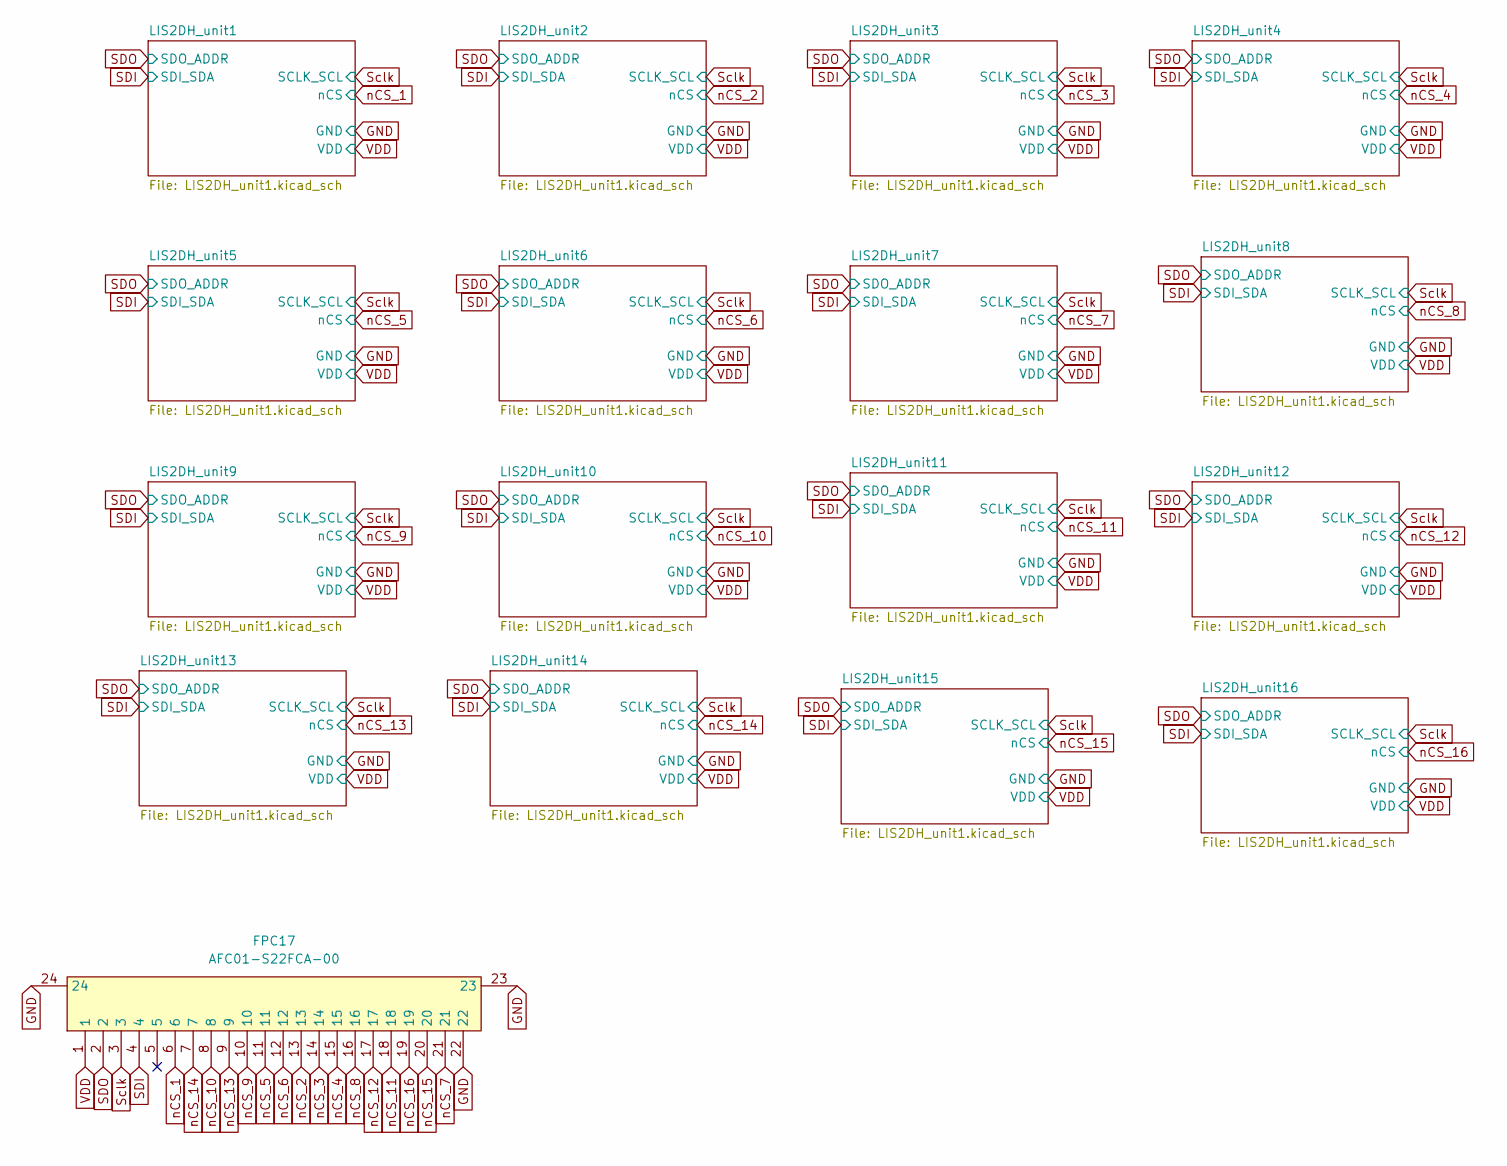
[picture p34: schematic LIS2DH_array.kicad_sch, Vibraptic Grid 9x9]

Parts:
FPC17: AFC01-S22FCA-00; FPC-SMD_P0.5-22P_FGS-XJ-H2.0; LCSC Part C262668

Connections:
GND: FPC17.22, FPC17.23, FPC17.24; also elsewhere on the board
SDI: FPC17.4; also elsewhere on the board
SDO: FPC17.2; also elsewhere on the board
Sclk: FPC17.3; also elsewhere on the board
VDD: FPC17.1; also elsewhere on the board
nCS_1: FPC17.6; also elsewhere on the board
nCS_2: FPC17.13; also elsewhere on the board
nCS_3: FPC17.14; also elsewhere on the board
nCS_4: FPC17.15; also elsewhere on the board
nCS_5: FPC17.11; also elsewhere on the board
nCS_6: FPC17.12; also elsewhere on the board
nCS_7: FPC17.21; also elsewhere on the board
nCS_8: FPC17.16; also elsewhere on the board
nCS_9: FPC17.10; also elsewhere on the board
nCS_10: FPC17.8; also elsewhere on the board
nCS_11: FPC17.18; also elsewhere on the board
nCS_12: FPC17.17; also elsewhere on the board
nCS_13: FPC17.9; also elsewhere on the board
nCS_14: FPC17.7; also elsewhere on the board
nCS_15: FPC17.20; also elsewhere on the board
nCS_16: FPC17.19; also elsewhere on the board

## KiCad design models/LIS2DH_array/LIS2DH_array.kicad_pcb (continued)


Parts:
C21: 100n; C_0402_1005Metric_Pad0.74x0.62mm_HandSolder; LCSC Part C1525
C22: 1uF; C_0402_1005Metric_Pad0.74x0.62mm_HandSolder; LCSC Part C52923
FPC9: HC-FPC-05-09-6RLTAG; FPC-SMD_6P-P0.50_HC-FPC-05-09-6RLTAG; LCSC Part C5213748
U9: LIS2DH12TR; LGA-12_L2.0-W2.0-P0.50-BL; LCSC Part C110926
U25: SN74LVC1G32DCKR; SOT-353_L2.1-W1.3-P0.65-LS2.3-BR; LCSC Part C7840

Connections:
/LIS2DH_unit9/INT1: U9.12 (INT1)
/LIS2DH_unit9/INT2: U9.11 (INT2)
GND: C21.2, C22.2, FPC9.1, FPC9.7, FPC9.8, U9.5 (RES), U9.6 (GND), U9.7 (GND), U9.8 (GND), U25.3 (GND); also elsewhere on the board
unnamed: U9.4 (SDA/SDI/SDO), U25.4 (Y)
SDI: FPC9.2, U25.2 (B); also elsewhere on the board
SDO: FPC9.3, U9.3 (SDO/SA0); also elsewhere on the board
Sclk: FPC9.5, U9.1 (SCL/SPC); also elsewhere on the board
VDD: C21.1, C22.1, FPC9.6, U9.9 (VDD), U9.10 (VDD_IO), U25.5 (VCC); also elsewhere on the board
nCS_9: FPC9.4, U9.2 (CS), U25.1 (A); also elsewhere on the board

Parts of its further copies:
C1, C3, C5, C7, C9, C11, C13, C15, C17, C19, C23, C25, C27, C29, C31: 100n; C_0402_1005Metric_Pad0.74x0.62mm_HandSolder; LCSC Part C1525
C2, C4, C6, C8, C10, C12, C14, C16, C18, C20, C24, C26, C28, C30, C32: 1uF; C_0402_1005Metric_Pad0.74x0.62mm_HandSolder; LCSC Part C52923
FPC1, FPC2, FPC3, FPC4, FPC5, FPC6, FPC7, FPC8, FPC10, FPC11, FPC12, FPC13, FPC14, FPC15, FPC16: HC-FPC-05-09-6RLTAG; FPC-SMD_6P-P0.50_HC-FPC-05-09-6RLTAG; LCSC Part C5213748
U1, U2, U3, U4, U5, U6, U7, U8, U10, U11, U12, U13, U14, U15, U16: LIS2DH12TR; LGA-12_L2.0-W2.0-P0.50-BL; LCSC Part C110926
U17, U18, U19, U20, U21, U22, U23, U24, U26, U27, U28, U29, U30, U31, U32: SN74LVC1G32DCKR; SOT-353_L2.1-W1.3-P0.65-LS2.3-BR; LCSC Part C7840

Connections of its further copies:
/LIS2DH_unit1/INT1: U1.12 (INT1)
/LIS2DH_unit1/INT2: U1.11 (INT2)
/LIS2DH_unit2/INT1: U2.12 (INT1)
/LIS2DH_unit2/INT2: U2.11 (INT2)
/LIS2DH_unit3/INT1: U3.12 (INT1)
/LIS2DH_unit3/INT2: U3.11 (INT2)
/LIS2DH_unit4/INT1: U4.12 (INT1)
/LIS2DH_unit4/INT2: U4.11 (INT2)
/LIS2DH_unit5/INT1: U5.12 (INT1)
/LIS2DH_unit5/INT2: U5.11 (INT2)
/LIS2DH_unit6/INT1: U6.12 (INT1)
/LIS2DH_unit6/INT2: U6.11 (INT2)
/LIS2DH_unit7/INT1: U7.12 (INT1)
/LIS2DH_unit7/INT2: U7.11 (INT2)
/LIS2DH_unit8/INT1: U8.12 (INT1)
/LIS2DH_unit8/INT2: U8.11 (INT2)
/LIS2DH_unit10/INT1: U10.12 (INT1)
/LIS2DH_unit10/INT2: U10.11 (INT2)
/LIS2DH_unit11/INT1: U11.12 (INT1)
/LIS2DH_unit11/INT2: U11.11 (INT2)
/LIS2DH_unit12/INT1: U12.12 (INT1)
/LIS2DH_unit12/INT2: U12.11 (INT2)
/LIS2DH_unit13/INT1: U13.12 (INT1)
/LIS2DH_unit13/INT2: U13.11 (INT2)
/LIS2DH_unit14/INT1: U14.12 (INT1)
/LIS2DH_unit14/INT2: U14.11 (INT2)
/LIS2DH_unit15/INT1: U15.12 (INT1)
/LIS2DH_unit15/INT2: U15.11 (INT2)
/LIS2DH_unit16/INT1: U16.12 (INT1)
/LIS2DH_unit16/INT2: U16.11 (INT2)
GND: C1.2, C2.2, C3.2, C4.2, C5.2, C6.2, C7.2, C8.2, C9.2, C10.2, C11.2, C12.2, C13.2, C14.2, C15.2, C16.2, C17.2, C18.2, C19.2, C20.2, C23.2, C24.2, C25.2, C26.2, C27.2, C28.2, C29.2, C30.2, C31.2, C32.2, FPC1.1, FPC1.7, FPC1.8, FPC2.1, FPC2.7, FPC2.8, FPC3.1, FPC3.7, FPC3.8, FPC4.1, FPC4.7, FPC4.8, FPC5.1, FPC5.7, FPC5.8, FPC6.1, FPC6.7, FPC6.8, FPC7.1, FPC7.7, FPC7.8, FPC8.1, FPC8.7, FPC8.8, FPC10.1, FPC10.7, FPC10.8, FPC11.1, FPC11.7, FPC11.8, FPC12.1, FPC12.7, FPC12.8, FPC13.1, FPC13.7, FPC13.8, FPC14.1, FPC14.7, FPC14.8, FPC15.1, FPC15.7, FPC15.8, FPC16.1, FPC16.7, FPC16.8, U1.5 (RES), U1.6 (GND), U1.7 (GND), U1.8 (GND), U2.5 (RES), U2.6 (GND), U2.7 (GND), U2.8 (GND), U3.5 (RES), U3.6 (GND), U3.7 (GND), U3.8 (GND), U4.5 (RES), U4.6 (GND), U4.7 (GND), U4.8 (GND), U5.5 (RES), U5.6 (GND), U5.7 (GND), U5.8 (GND), U6.5 (RES), U6.6 (GND), U6.7 (GND), U6.8 (GND), U7.5 (RES), U7.6 (GND), U7.7 (GND), U7.8 (GND), U8.5 (RES), U8.6 (GND), U8.7 (GND), U8.8 (GND), U10.5 (RES), U10.6 (GND), U10.7 (GND), U10.8 (GND), U11.5 (RES), U11.6 (GND), U11.7 (GND), U11.8 (GND), U12.5 (RES), U12.6 (GND), U12.7 (GND), U12.8 (GND), U13.5 (RES), U13.6 (GND), U13.7 (GND), U13.8 (GND), U14.5 (RES), U14.6 (GND), U14.7 (GND), U14.8 (GND), U15.5 (RES), U15.6 (GND), U15.7 (GND), U15.8 (GND), U16.5 (RES), U16.6 (GND), U16.7 (GND), U16.8 (GND), U17.3 (GND), U18.3 (GND), U19.3 (GND), U20.3 (GND), U21.3 (GND), U22.3 (GND), U23.3 (GND), U24.3 (GND), U26.3 (GND), U27.3 (GND), U28.3 (GND), U29.3 (GND), U30.3 (GND), U31.3 (GND), U32.3 (GND); also elsewhere on the board
unnamed: U1.4 (SDA/SDI/SDO), U17.4 (Y)
unnamed: U10.4 (SDA/SDI/SDO), U26.4 (Y)
unnamed: U11.4 (SDA/SDI/SDO), U27.4 (Y)
unnamed: U12.4 (SDA/SDI/SDO), U28.4 (Y)
unnamed: U13.4 (SDA/SDI/SDO), U29.4 (Y)
unnamed: U14.4 (SDA/SDI/SDO), U30.4 (Y)
unnamed: U15.4 (SDA/SDI/SDO), U31.4 (Y)
unnamed: U16.4 (SDA/SDI/SDO), U32.4 (Y)
unnamed: U2.4 (SDA/SDI/SDO), U18.4 (Y)
unnamed: U3.4 (SDA/SDI/SDO), U19.4 (Y)
unnamed: U4.4 (SDA/SDI/SDO), U20.4 (Y)
unnamed: U5.4 (SDA/SDI/SDO), U21.4 (Y)
unnamed: U6.4 (SDA/SDI/SDO), U22.4 (Y)
unnamed: U7.4 (SDA/SDI/SDO), U23.4 (Y)
unnamed: U8.4 (SDA/SDI/SDO), U24.4 (Y)
SDI: FPC1.2, FPC2.2, FPC3.2, FPC4.2, FPC5.2, FPC6.2, FPC7.2, FPC8.2, FPC10.2, FPC11.2, FPC12.2, FPC13.2, FPC14.2, FPC15.2, FPC16.2, U17.2 (B), U18.2 (B), U19.2 (B), U20.2 (B), U21.2 (B), U22.2 (B), U23.2 (B), U24.2 (B), U26.2 (B), U27.2 (B), U28.2 (B), U29.2 (B), U30.2 (B), U31.2 (B), U32.2 (B); also elsewhere on the board
SDO: FPC1.3, FPC2.3, FPC3.3, FPC4.3, FPC5.3, FPC6.3, FPC7.3, FPC8.3, FPC10.3, FPC11.3, FPC12.3, FPC13.3, FPC14.3, FPC15.3, FPC16.3, U1.3 (SDO/SA0), U2.3 (SDO/SA0), U3.3 (SDO/SA0), U4.3 (SDO/SA0), U5.3 (SDO/SA0), U6.3 (SDO/SA0), U7.3 (SDO/SA0), U8.3 (SDO/SA0), U10.3 (SDO/SA0), U11.3 (SDO/SA0), U12.3 (SDO/SA0), U13.3 (SDO/SA0), U14.3 (SDO/SA0), U15.3 (SDO/SA0), U16.3 (SDO/SA0); also elsewhere on the board
Sclk: FPC1.5, FPC2.5, FPC3.5, FPC4.5, FPC5.5, FPC6.5, FPC7.5, FPC8.5, FPC10.5, FPC11.5, FPC12.5, FPC13.5, FPC14.5, FPC15.5, FPC16.5, U1.1 (SCL/SPC), U2.1 (SCL/SPC), U3.1 (SCL/SPC), U4.1 (SCL/SPC), U5.1 (SCL/SPC), U6.1 (SCL/SPC), U7.1 (SCL/SPC), U8.1 (SCL/SPC), U10.1 (SCL/SPC), U11.1 (SCL/SPC), U12.1 (SCL/SPC), U13.1 (SCL/SPC), U14.1 (SCL/SPC), U15.1 (SCL/SPC), U16.1 (SCL/SPC); also elsewhere on the board
VDD: C1.1, C2.1, C3.1, C4.1, C5.1, C6.1, C7.1, C8.1, C9.1, C10.1, C11.1, C12.1, C13.1, C14.1, C15.1, C16.1, C17.1, C18.1, C19.1, C20.1, C23.1, C24.1, C25.1, C26.1, C27.1, C28.1, C29.1, C30.1, C31.1, C32.1, FPC1.6, FPC2.6, FPC3.6, FPC4.6, FPC5.6, FPC6.6, FPC7.6, FPC8.6, FPC10.6, FPC11.6, FPC12.6, FPC13.6, FPC14.6, FPC15.6, FPC16.6, U1.9 (VDD), U1.10 (VDD_IO), U2.9 (VDD), U2.10 (VDD_IO), U3.9 (VDD), U3.10 (VDD_IO), U4.9 (VDD), U4.10 (VDD_IO), U5.9 (VDD), U5.10 (VDD_IO), U6.9 (VDD), U6.10 (VDD_IO), U7.9 (VDD), U7.10 (VDD_IO), U8.9 (VDD), U8.10 (VDD_IO), U10.9 (VDD), U10.10 (VDD_IO), U11.9 (VDD), U11.10 (VDD_IO), U12.9 (VDD), U12.10 (VDD_IO), U13.9 (VDD), U13.10 (VDD_IO), U14.9 (VDD), U14.10 (VDD_IO), U15.9 (VDD), U15.10 (VDD_IO), U16.9 (VDD), U16.10 (VDD_IO), U17.5 (VCC), U18.5 (VCC), U19.5 (VCC), U20.5 (VCC), U21.5 (VCC), U22.5 (VCC), U23.5 (VCC), U24.5 (VCC), U26.5 (VCC), U27.5 (VCC), U28.5 (VCC), U29.5 (VCC), U30.5 (VCC), U31.5 (VCC), U32.5 (VCC); also elsewhere on the board
nCS_1: FPC1.4, U1.2 (CS), U17.1 (A); also elsewhere on the board
nCS_2: FPC2.4, U2.2 (CS), U18.1 (A); also elsewhere on the board
nCS_3: FPC3.4, U3.2 (CS), U19.1 (A); also elsewhere on the board
nCS_4: FPC4.4, U4.2 (CS), U20.1 (A); also elsewhere on the board
nCS_5: FPC5.4, U5.2 (CS), U21.1 (A); also elsewhere on the board
nCS_6: FPC6.4, U6.2 (CS), U22.1 (A); also elsewhere on the board
nCS_7: FPC7.4, U7.2 (CS), U23.1 (A); also elsewhere on the board
nCS_8: FPC8.4, U8.2 (CS), U24.1 (A); also elsewhere on the board
nCS_10: FPC10.4, U10.2 (CS), U26.1 (A); also elsewhere on the board
nCS_11: FPC11.4, U11.2 (CS), U27.1 (A); also elsewhere on the board
nCS_12: FPC12.4, U12.2 (CS), U28.1 (A); also elsewhere on the board
nCS_13: FPC13.4, U13.2 (CS), U29.1 (A); also elsewhere on the board
nCS_14: FPC14.4, U14.2 (CS), U30.1 (A); also elsewhere on the board
nCS_15: FPC15.4, U15.2 (CS), U31.1 (A); also elsewhere on the board
nCS_16: FPC16.4, U16.2 (CS), U32.1 (A); also elsewhere on the board


Board: 2 copper layers, 113.0 x 113.0 mm, 81 parts (0 on the bottom side), 37 nets.

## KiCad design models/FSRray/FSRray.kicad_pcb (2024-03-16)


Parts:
ADC1, ADC2: MAX11632EEGT
C1, C2: 100n; C0603
H1, H5: MountingHole; MountingHole_3.2mm_M3
J1, J2, J3, J4, J5: measuring_input4; fcp_vertical_ULP94V0
J11: teensy_right; PinSocket_1x24_P2.54mm_Vertical
J12: teensy_left; PinSocket_1x24_P2.54mm_Vertical
J17: usb_B; SS52300001; Mouser Part Number 530-SS-52300-001
MUX1, MUX2: CD74HC4067SM; SSOP-24_5.3x8.2mm_P0.65mm
RN1, RN2, RN3, RN4, RN5, RN6, RN7, RN8: R_Pack04; R_Array_Convex_4x0402

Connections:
+3.3V: J5.13, J12.15
+5V: ADC1.19 (VDD), ADC2.19 (VDD), J11.1, J17.1 (VBUS), MUX1.1 (COM), MUX1.24 (VCC), MUX2.1 (COM), MUX2.24 (VCC)
/CS1: ADC1.20 (~CS), J12.11
/CS2: ADC2.20 (~CS), J12.20
/CSA1: J5.1, J11.4
/CSA2: J5.2, J11.5
/CSA3: J5.3, J11.6
/CSA4: J5.4, J11.7
/CSA5: J5.5, J11.8
/CSA6: J5.6, J11.9
/CSA7: J5.7, J11.10
/CSA8: J5.8, J11.11
/EN1: J11.24, MUX1.15 (~E)
/EN2: J11.23, MUX2.15 (~E)
/EOC1: ADC1.24 (~EOC), J12.10
/EOC2: ADC2.24 (~EOC), J12.17
/MISO: ADC1.23 (DOUT), ADC2.23 (DOUT), J12.14
/MISO1: J5.14, J12.3
/MOSI: ADC1.22 (DIN), ADC2.22 (DIN), J12.13
/MOSI1: J5.16, J12.18
/S0: J12.24, MUX1.10 (S0), MUX2.10 (S0)
/S1: J12.23, MUX1.11 (S1), MUX2.11 (S1)
/S2: J12.22, MUX1.14 (S2), MUX2.14 (S2)
/S3: J12.21, MUX1.13 (S3), MUX2.13 (S3)
/SCLK: ADC1.21 (SCLK), ADC2.21 (SCLK), J11.14
/SCLK1: J5.15, J12.19
GND: ADC1.18 (GND), ADC2.18 (GND), C1.2, C2.2, J5.12, J11.2, J11.15, J12.1, J17.4 (GND), MUX1.12 (GND), MUX2.12 (GND), RN1.1 (R1.1), RN1.2 (R2.1), RN1.3 (R3.1), RN1.4 (R4.1), RN2.1 (R1.1), RN2.2 (R2.1), RN2.3 (R3.1), RN2.4 (R4.1), RN3.1 (R1.1), RN3.2 (R2.1), RN3.3 (R3.1), RN3.4 (R4.1), RN4.1 (R1.1), RN4.2 (R2.1), RN4.3 (R3.1), RN4.4 (R4.1), RN5.1 (R1.1), RN5.2 (R2.1), RN5.3 (R3.1), RN5.4 (R4.1), RN6.1 (R1.1), RN6.2 (R2.1), RN6.3 (R3.1), RN6.4 (R4.1), RN7.1 (R1.1), RN7.2 (R2.1), RN7.3 (R3.1), RN7.4 (R4.1), RN8.1 (R1.1), RN8.2 (R2.1), RN8.3 (R3.1), RN8.4 (R4.1)
unnamed: ADC1.1 (AIN0), J4.1, RN1.8 (R1.2)
unnamed: ADC1.2 (AIN1), J4.2, RN1.7 (R2.2)
unnamed: ADC1.3 (AIN2), J4.3, RN1.6 (R3.2)
unnamed: ADC1.4 (AIN3), J4.4, RN1.5 (R4.2)
unnamed: ADC1.5 (AIN4), J4.5, RN2.8 (R1.2)
unnamed: ADC1.6 (AIN5), J4.6, RN2.7 (R2.2)
unnamed: ADC1.7 (AIN6), J4.7, RN2.6 (R3.2)
unnamed: ADC1.8 (AIN7), J4.8, RN2.5 (R4.2)
unnamed: ADC1.9 (AIN8), J4.9, RN3.8 (R1.2)
unnamed: ADC1.10 (AIN9), J4.10, RN3.7 (R2.2)
unnamed: ADC1.11 (AIN10), J4.11, RN3.6 (R3.2)
unnamed: ADC1.12 (AIN11), J4.12, RN3.5 (R4.2)
unnamed: ADC1.13 (AIN12), J4.13, RN4.8 (R1.2)
unnamed: ADC1.14 (AIN13), J4.14, RN4.7 (R2.2)
unnamed: ADC1.15 (AIN14), J4.15, RN4.6 (R3.2)
unnamed: ADC1.17 (REF), C1.1
unnamed: ADC1.16 (~CNVST/AIN15), J4.16, RN4.5 (R4.2)
unnamed: ADC2.1 (AIN0), J3.1, RN5.8 (R1.2)
unnamed: ADC2.2 (AIN1), J3.2, RN5.7 (R2.2)
unnamed: ADC2.3 (AIN2), J3.3, RN5.6 (R3.2)
unnamed: ADC2.4 (AIN3), J3.4, RN5.5 (R4.2)
unnamed: ADC2.5 (AIN4), J3.5, RN6.8 (R1.2)
unnamed: ADC2.6 (AIN5), J3.6, RN6.7 (R2.2)
unnamed: ADC2.7 (AIN6), J3.7, RN6.6 (R3.2)
unnamed: ADC2.8 (AIN7), J3.8, RN6.5 (R4.2)
unnamed: ADC2.9 (AIN8), J3.9, RN7.8 (R1.2)
unnamed: ADC2.10 (AIN9), J3.10, RN7.7 (R2.2)
unnamed: ADC2.11 (AIN10), J3.11, RN7.6 (R3.2)
unnamed: ADC2.12 (AIN11), J3.12, RN7.5 (R4.2)
unnamed: ADC2.13 (AIN12), J3.13, RN8.8 (R1.2)
unnamed: ADC2.14 (AIN13), J3.14, RN8.7 (R2.2)
unnamed: ADC2.15 (AIN14), J3.15, RN8.6 (R3.2)
unnamed: ADC2.17 (REF), C2.1
unnamed: ADC2.16 (~CNVST/AIN15), J3.16, RN8.5 (R4.2)
unnamed: J1.1, MUX2.16 (I15)
unnamed: J1.2, MUX2.17 (I14)
unnamed: J1.3, MUX2.18 (I13)
unnamed: J1.4, MUX2.19 (I12)
unnamed: J1.5, MUX2.20 (I11)
unnamed: J1.6, MUX2.21 (I10)
unnamed: J1.7, MUX2.22 (I9)
unnamed: J1.8, MUX2.23 (I8)
unnamed: J1.9, MUX2.2 (I7)
unnamed: J1.10, MUX2.3 (I6)
unnamed: J1.11, MUX2.4 (I5)
unnamed: J1.12, MUX2.5 (I4)
unnamed: J1.13, MUX2.6 (I3)
unnamed: J1.14, MUX2.7 (I2)
unnamed: J1.15, MUX2.8 (I1)
unnamed: J1.16, MUX2.9 (I0)
unnamed: J2.1, MUX1.16 (I15)
unnamed: J2.2, MUX1.17 (I14)
unnamed: J2.3, MUX1.18 (I13)
unnamed: J2.4, MUX1.19 (I12)
unnamed: J2.5, MUX1.20 (I11)
unnamed: J2.6, MUX1.21 (I10)
unnamed: J2.7, MUX1.22 (I9)
unnamed: J2.8, MUX1.23 (I8)
unnamed: J2.9, MUX1.2 (I7)
unnamed: J2.10, MUX1.3 (I6)
unnamed: J2.11, MUX1.4 (I5)
unnamed: J2.12, MUX1.5 (I4)
unnamed: J2.13, MUX1.6 (I3)
unnamed: J2.14, MUX1.7 (I2)
unnamed: J2.15, MUX1.8 (I1)
unnamed: J2.16, MUX1.9 (I0)

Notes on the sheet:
ADCs
USB B Power supply
Accelerometers conn.
Teensy conn.
Scanning mux


Board: 4 copper layers, 82.0 x 47.0 mm, 24 parts (1 on the bottom side), 93 nets.

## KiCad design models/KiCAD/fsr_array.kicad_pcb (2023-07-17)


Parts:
ADC1, ADC2: MAX11632EEGT
C1, C2: 100n; C0603
H1, H2, H3, H4, H5: MountingHole; MountingHole_3.2mm_M3
J1: scanning_ref1; PinHeader_1x08_P2.54mm_Vertical
J2: scanning_ref2; PinHeader_1x08_P2.54mm_Vertical
J3: scanning_ref3; PinHeader_1x08_P2.54mm_Vertical
J4: scanning_ref4; PinHeader_1x08_P2.54mm_Vertical
J5: measuring_input1; PinHeader_1x08_P2.54mm_Vertical
J6: measuring_input2; PinHeader_1x08_P2.54mm_Vertical
J7: measuring_input3; PinHeader_1x08_P2.54mm_Vertical
J8: measuring_input4; PinHeader_1x08_P2.54mm_Vertical
J9: com_mux; PinHeader_1x08_P2.54mm_Vertical
J10: com_adc; PinHeader_1x09_P2.54mm_Vertical
J11: teensy_right; PinSocket_1x24_P2.54mm_Vertical
J12: teensy_left; PinSocket_1x24_P2.54mm_Vertical
J13: com_acc2; PinHeader_2x05_P1.27mm_Vertical
J14: com_acc1; PinHeader_2x05_P1.27mm_Vertical
J15: com_acc3; PinHeader_2x05_P1.27mm_Vertical
J16: com_acc4; PinHeader_2x05_P1.27mm_Vertical
J17: usb_B; SS52300001; Mouser Part Number 530-SS-52300-001
MUX1, MUX2: CD74HC4067SM; SSOP-24_5.3x8.2mm_P0.65mm
U$1, U$2, U$3, U$4, U$5, U$6, U$7, U$8, U$9, U$10, U$11, U$12, U$13, U$14, U$15, U$16, U$17, U$18, U$19, U$20, U$21, U$22, U$23, U$24, U$25, U$26, U$27, U$28, U$29, U$30, U$31, U$32, U$33, U$34, U$35, U$36, U$37, U$38, U$39, U$40, U$41, U$42, U$43, U$44, U$45, U$46, U$47, U$48, U$49, U$50, U$51, U$52, U$53, U$54, U$55, U$56, U$57, U$58, U$59, U$60, U$61, U$62, U$63, U$64: HALF_RES; HALP_RES

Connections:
+3.3V: J12.15, J13.1, J14.1, J15.1, J16.1
/CS1: ADC1.20 (~CS), J10.6, J12.11
/CS2: ADC2.20 (~CS), J10.7, J12.12
/CSA1: J11.3, J14.9
/CSA2: J11.4, J13.9
/CSA3: J11.7, J15.9
/CSA4: J11.8, J16.9
/EN1: J9.5, J12.8, MUX1.15 (~E)
/EN2: J9.6, J12.9, MUX2.15 (~E)
/EOC1: ADC1.24 (~EOC), J10.1, J12.10
/EOC2: ADC2.24 (~EOC), J10.2, J12.17
/INTA1: J11.20, J13.6, J14.6, J15.6, J16.6
/INTA2: J11.21, J13.7, J14.7, J15.7, J16.7
/L2: J17.2
/L3: J17.3
/M1: J17.MH1
/M2: J17.MH2
/MISO: ADC1.23 (DOUT), ADC2.23 (DOUT), J10.3, J12.14
/MISO1: J12.3, J13.3, J14.3, J15.3, J16.3
/MOSI: ADC1.22 (DIN), ADC2.22 (DIN), J10.4, J12.13
/MOSI1: J12.18, J13.4, J14.4, J15.4, J16.4
/S0: J9.1, J12.4, MUX1.10 (S0), MUX2.10 (S0)
/S1: J9.2, J12.5, MUX1.11 (S1), MUX2.11 (S1)
/S2: J9.3, J12.6, MUX1.14 (S2), MUX2.14 (S2)
/S3: J9.4, J12.7, MUX1.13 (S3), MUX2.13 (S3)
/SCK1: J12.19, J13.5, J14.5, J15.5, J16.5
/SCLK: ADC1.21 (SCLK), ADC2.21 (SCLK), J10.5, J11.14
/TRIGA: J11.24, J13.2, J14.2, J15.2, J16.2
unnamed: ADC1.1 (AIN0), J5.1, U$16.P$1
unnamed: ADC1.2 (AIN1), J5.2, U$14.P$1
unnamed: ADC1.3 (AIN2), J5.3, U$12.P$1
unnamed: ADC1.4 (AIN3), J5.4, U$10.P$1
unnamed: ADC1.5 (AIN4), J5.5, U$8.P$1
unnamed: ADC1.6 (AIN5), J5.6, U$6.P$1
unnamed: ADC1.7 (AIN6), J5.7, U$4.P$1
unnamed: ADC1.8 (AIN7), J5.8, U$2.P$1
unnamed: ADC1.9 (AIN8), J6.1, U$32.P$1
unnamed: ADC1.10 (AIN9), J6.2, U$30.P$1
unnamed: ADC1.11 (AIN10), J6.3, U$28.P$1
unnamed: ADC1.12 (AIN11), J6.4, U$26.P$1
unnamed: ADC1.13 (AIN12), J6.5, U$24.P$1
unnamed: ADC1.14 (AIN13), J6.6, U$22.P$1
unnamed: ADC1.15 (AIN14), J6.7, U$20.P$1
unnamed: ADC1.17 (REF), C1.1
unnamed: ADC1.16 (~CNVST/AIN15), J6.8, U$18.P$1
unnamed: ADC2.1 (AIN0), J7.1, U$48.P$1
unnamed: ADC2.2 (AIN1), J7.2, U$46.P$1
unnamed: ADC2.3 (AIN2), J7.3, U$44.P$1
unnamed: ADC2.4 (AIN3), J7.4, U$42.P$1
unnamed: ADC2.5 (AIN4), J7.5, U$40.P$1
unnamed: ADC2.6 (AIN5), J7.6, U$38.P$1
unnamed: ADC2.7 (AIN6), J7.7, U$36.P$1
unnamed: ADC2.8 (AIN7), J7.8, U$34.P$1
unnamed: ADC2.9 (AIN8), J8.1, U$64.P$1
unnamed: ADC2.10 (AIN9), J8.2, U$62.P$1
unnamed: ADC2.11 (AIN10), J8.3, U$60.P$1
unnamed: ADC2.12 (AIN11), J8.4, U$58.P$1
unnamed: ADC2.13 (AIN12), J8.5, U$56.P$1
unnamed: ADC2.14 (AIN13), J8.6, U$54.P$1
unnamed: ADC2.15 (AIN14), J8.7, U$52.P$1
unnamed: ADC2.17 (REF), C2.1
unnamed: ADC2.16 (~CNVST/AIN15), J8.8, U$50.P$1
unnamed: J1.1, MUX1.9 (I0)
unnamed: J1.2, MUX1.8 (I1)
unnamed: J1.3, MUX1.7 (I2)
unnamed: J1.4, MUX1.6 (I3)
unnamed: J1.5, MUX1.5 (I4)
unnamed: J1.6, MUX1.4 (I5)
unnamed: J1.7, MUX1.3 (I6)
unnamed: J1.8, MUX1.2 (I7)
unnamed: J2.1, MUX1.23 (I8)
unnamed: J2.2, MUX1.22 (I9)
unnamed: J2.3, MUX1.21 (I10)
unnamed: J2.4, MUX1.20 (I11)
unnamed: J2.5, MUX1.19 (I12)
unnamed: J2.6, MUX1.18 (I13)
unnamed: J2.7, MUX1.17 (I14)
unnamed: J2.8, MUX1.16 (I15)
unnamed: J3.1, MUX2.9 (I0)
unnamed: J3.2, MUX2.8 (I1)
unnamed: J3.3, MUX2.7 (I2)
unnamed: J3.4, MUX2.6 (I3)
unnamed: J3.5, MUX2.5 (I4)
unnamed: J3.6, MUX2.4 (I5)
unnamed: J3.7, MUX2.3 (I6)
unnamed: J3.8, MUX2.2 (I7)
unnamed: J4.1, MUX2.23 (I8)
unnamed: J4.2, MUX2.22 (I9)
unnamed: J4.3, MUX2.21 (I10)
unnamed: J4.4, MUX2.20 (I11)
unnamed: J4.5, MUX2.19 (I12)
unnamed: J4.6, MUX2.18 (I13)
unnamed: J4.7, MUX2.17 (I14)
unnamed: J4.8, MUX2.16 (I15)

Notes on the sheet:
ADCs
USB B Power supply
Accelerometers conn.
Scanning mux
Teensy conn.

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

Board: 4 copper layers, 100.0 x 100.0 mm, 92 parts (0 on the bottom side), 92 nets.

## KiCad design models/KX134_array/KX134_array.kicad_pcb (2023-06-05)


Board: 2 copper layers, 85.0 x 89.5 mm, 39 parts (0 on the bottom side), 32 nets.

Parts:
C1, C3, C5, C7, C9, C11, C13, C15, C17: 100n; C_01005_0402Metric
C2, C4, C6, C8, C10, C12, C14, C16, C18: 1u; C_01005_0402Metric
J1, J2, J3, J4, J5, J6, J7, J8, J9: Conn_01x08_Socket; PinSocket_1x08_P1.27mm_Vertical
J10: Conn_01x09_Socket; PinHeader_1x09_P2.54mm_Vertical
J11: Conn_01x03_Socket; PinHeader_1x03_P2.54mm_Vertical
J12: Conn_01x02_Socket; PinHeader_1x02_P2.54mm_Vertical
U1, U2, U3, U4, U5, U6, U7, U8, U9: kx134; KX134-1211

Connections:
GND: C1.2, C2.1, C3.2, C4.1, C5.2, C6.1, C7.2, C8.1, C9.2, C10.1, C11.2, C12.1, C13.2, C14.1, C15.2, C16.1, C17.2, C18.1, J1.1, J2.1, J3.1, J4.1, J5.1, J6.1, J7.1, J8.1, J9.1, J12.2, U1.8 (GND), U1.9 (GND), U2.8 (GND), U2.9 (GND), U3.8 (GND), U3.9 (GND), U4.8 (GND), U4.9 (GND), U5.8 (GND), U5.9 (GND), U6.8 (GND), U6.9 (GND), U7.8 (GND), U7.9 (GND), U8.8 (GND), U8.9 (GND), U9.8 (GND), U9.9 (GND)
INT1_1: J1.2, U1.5 (INT1)
INT1_2: J2.2, U2.5 (INT1)
INT1_3: J3.2, U3.5 (INT1)
INT1_4: J4.2, U4.5 (INT1)
INT1_5: J5.2, U5.5 (INT1)
INT1_6: J6.2, U6.5 (INT1)
INT1_7: J7.2, U7.5 (INT1)
INT1_8: J8.2, U8.5 (INT1)
INT1_9: J9.2, U9.5 (INT1)
SDI: J1.6, J2.6, J3.6, J4.6, J5.6, J6.6, J7.6, J8.6, J9.6, J11.3, U1.2 (SDI/SDA), U1.11 (NC), U2.2 (SDI/SDA), U2.11 (NC), U3.2 (SDI/SDA), U3.11 (NC), U4.2 (SDI/SDA), U4.11 (NC), U5.2 (SDI/SDA), U5.11 (NC), U6.2 (SDI/SDA), U6.11 (NC), U7.2 (SDI/SDA), U7.11 (NC), U8.2 (SDI/SDA), U8.11 (NC), U9.2 (SDI/SDA), U9.11 (NC)
SDO: J1.8, J2.8, J3.8, J4.8, J5.8, J6.8, J7.8, J8.8, J9.8, J11.1, U1.1 (SDO/ADDR), U2.1 (SDO/ADDR), U3.1 (SDO/ADDR), U4.1 (SDO/ADDR), U5.1 (SDO/ADDR), U6.1 (SDO/ADDR), U7.1 (SDO/ADDR), U8.1 (SDO/ADDR), U9.1 (SDO/ADDR)
Sclk: J1.7, J2.7, J3.7, J4.7, J5.7, J6.7, J7.7, J8.7, J9.7, J11.2, U1.12 (SCLK/SCL), U2.12 (SCLK/SCL), U3.12 (SCLK/SCL), U4.12 (SCLK/SCL), U5.12 (SCLK/SCL), U6.12 (SCLK/SCL), U7.12 (SCLK/SCL), U8.12 (SCLK/SCL), U9.12 (SCLK/SCL)
TRIG_1: J1.4, U1.4 (TRIG)
TRIG_2: J2.4, U2.4 (TRIG)
TRIG_3: J3.4, U3.4 (TRIG)
TRIG_4: J4.4, U4.4 (TRIG)
TRIG_5: J5.4, U5.4 (TRIG)
TRIG_6: J6.4, U6.4 (TRIG)
TRIG_7: J7.4, U7.4 (TRIG)
TRIG_8: J8.4, U8.4 (TRIG)
TRIG_9: J9.4, U9.4 (TRIG)
VDD: C1.1, C2.2, C3.1, C4.2, C5.1, C6.2, C7.1, C8.2, C9.1, C10.2, C11.1, C12.2, C13.1, C14.2, C15.1, C16.2, C17.1, C18.2, J1.3, J2.3, J3.3, J4.3, J5.3, J6.3, J7.3, J8.3, J9.3, J12.1, U1.3 (IO_VDD), U1.7 (VDD), U2.3 (IO_VDD), U2.7 (VDD), U3.3 (IO_VDD), U3.7 (VDD), U4.3 (IO_VDD), U4.7 (VDD), U5.3 (IO_VDD), U5.7 (VDD), U6.3 (IO_VDD), U6.7 (VDD), U7.3 (IO_VDD), U7.7 (VDD), U8.3 (IO_VDD), U8.7 (VDD), U9.3 (IO_VDD), U9.7 (VDD)
nCS_1: J1.5, J10.8, U1.10 (nCS)
nCS_2: J2.5, J10.9, U2.10 (nCS)
nCS_3: J3.5, J10.2, U3.10 (nCS)
nCS_4: J4.5, J10.1, U4.10 (nCS)
nCS_5: J5.5, J10.5, U5.10 (nCS)
nCS_6: J6.5, J10.7, U6.10 (nCS)
nCS_7: J7.5, J10.4, U7.10 (nCS)
nCS_8: J8.5, J10.3, U8.10 (nCS)
nCS_9: J9.5, J10.6, U9.10 (nCS)

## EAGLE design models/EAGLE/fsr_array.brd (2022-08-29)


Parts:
C1, C2: C-EUC0603; C0603
CPLX1: LOGO
IC1, IC2: CD74HC4067SM96G4; SOP65P780X200-24N
IC3, IC4: MAX11632EEG+; SOP64P602X175-24N
U$1, U$2, U$3, U$4, U$5, U$6, U$7, U$8, U$9, U$10, U$11, U$12, U$13, U$14, U$15, U$16, U$17, U$18, U$19, U$20, U$21, U$22, U$23, U$24, U$25, U$26, U$27, U$28, U$29, U$30, U$31, U$32, U$33, U$34, U$35, U$36, U$37, U$38, U$39, U$40, U$41, U$42, U$43, U$44, U$45, U$46, U$47, U$48, U$49, U$50, U$51, U$52, U$53, U$54, U$55, U$56, U$57, U$58, U$59, U$60, U$61, U$62, U$63, U$64: HALF_RES; HALP_RES
X1, X2, X3, X4, X5, X6, X7, X8, X9: 22-23-2081
X10: 22-23-2091

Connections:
CS1: IC3.20 (!CS), X10.6
CS2: IC4.20 (!CS), X10.7
DIN: IC3.22 (DIN), IC4.22 (DIN), X10.4
DOUT: IC3.23 (DOUT), IC4.23 (DOUT), X10.3
EN1: IC1.15 (!E), X9.5
EN2: IC2.15 (!E), X9.6
EOC1: IC3.24 (!EOC), X10.1
EOC2: IC4.24 (!EOC), X10.2
GND: C1.2, C2.2, IC1.12 (GND), IC2.12 (GND), IC3.18 (GND), IC4.18 (GND), U$1.P$1, U$3.P$1, U$5.P$1, U$7.P$1, U$9.P$1, U$11.P$1, U$13.P$1, U$15.P$1, U$17.P$1, U$19.P$1, U$21.P$1, U$23.P$1, U$25.P$1, U$27.P$1, U$29.P$1, U$31.P$1, U$33.P$1, U$35.P$1, U$37.P$1, U$39.P$1, U$41.P$1, U$43.P$1, U$45.P$1, U$47.P$1, U$49.P$1, U$51.P$1, U$53.P$1, U$55.P$1, U$57.P$1, U$59.P$1, U$61.P$1, U$63.P$1, X9.8, X10.9
unnamed: IC1.9 (I0), X1.1
unnamed: IC1.8 (I1), X1.2
unnamed: IC1.7 (I2), X1.3
unnamed: IC1.6 (I3), X1.4
unnamed: IC1.5 (I4), X1.5
unnamed: IC1.4 (I5), X1.6
unnamed: IC1.3 (I6), X1.7
unnamed: IC1.2 (I7), X1.8
unnamed: IC1.23 (I8), X2.1
unnamed: IC1.22 (I9), X2.2
unnamed: IC1.21 (I10), X2.3
unnamed: IC1.20 (I11), X2.4
unnamed: IC1.19 (I12), X2.5
unnamed: IC1.18 (I13), X2.6
unnamed: IC1.17 (I14), X2.7
unnamed: IC1.16 (I15), X2.8
unnamed: IC2.9 (I0), X3.1
unnamed: IC2.8 (I1), X3.2
unnamed: IC2.7 (I2), X3.3
unnamed: IC2.6 (I3), X3.4
unnamed: IC2.5 (I4), X3.5
unnamed: IC2.4 (I5), X3.6
unnamed: IC2.3 (I6), X3.7
unnamed: IC2.2 (I7), X3.8
unnamed: IC2.23 (I8), X4.1
unnamed: IC2.22 (I9), X4.2
unnamed: IC2.21 (I10), X4.3
unnamed: IC2.20 (I11), X4.4
unnamed: IC2.19 (I12), X4.5
unnamed: IC2.18 (I13), X4.6
unnamed: IC2.17 (I14), X4.7
unnamed: IC2.16 (I15), X4.8
unnamed: IC3.1 (AIN0), U$16.P$1, X5.1
unnamed: IC3.2 (AIN1), U$14.P$1, X5.2
unnamed: IC3.3 (AIN2), U$12.P$1, X5.3
unnamed: IC3.4 (AIN3), U$10.P$1, X5.4
unnamed: IC3.5 (AIN4), U$8.P$1, X5.5
unnamed: IC3.6 (AIN5), U$6.P$1, X5.6
unnamed: IC3.7 (AIN6), U$4.P$1, X5.7
unnamed: IC3.8 (AIN7), U$2.P$1, X5.8
unnamed: IC3.9 (AIN8), U$32.P$1, X6.1
unnamed: IC3.10 (AIN9), U$30.P$1, X6.2
unnamed: IC3.11 (AIN10), U$28.P$1, X6.3
unnamed: IC3.12 (AIN11), U$26.P$1, X6.4
unnamed: IC3.13 (AIN12), U$24.P$1, X6.5
unnamed: IC3.14 (AIN13), U$22.P$1, X6.6
unnamed: IC3.15 (AIN14), U$20.P$1, X6.7
unnamed: IC3.16 (!CNVST!/AIN15), U$18.P$1, X6.8
unnamed: IC4.1 (AIN0), U$48.P$1, X7.1
unnamed: IC4.2 (AIN1), U$46.P$1, X7.2
unnamed: IC4.3 (AIN2), U$44.P$1, X7.3
unnamed: IC4.4 (AIN3), U$42.P$1, X7.4
unnamed: IC4.5 (AIN4), U$40.P$1, X7.5
unnamed: IC4.6 (AIN5), U$38.P$1, X7.6
unnamed: IC4.7 (AIN6), U$36.P$1, X7.7
unnamed: IC4.8 (AIN7), U$34.P$1, X7.8
unnamed: IC4.9 (AIN8), U$64.P$1, X8.1
unnamed: IC4.10 (AIN9), U$62.P$1, X8.2
unnamed: IC4.11 (AIN10), U$60.P$1, X8.3
unnamed: IC4.12 (AIN11), U$58.P$1, X8.4
unnamed: IC4.13 (AIN12), U$56.P$1, X8.5
unnamed: IC4.14 (AIN13), U$54.P$1, X8.6
unnamed: IC4.15 (AIN14), U$52.P$1, X8.7
unnamed: IC4.16 (!CNVST!/AIN15), U$50.P$1, X8.8
unnamed: C1.1, IC3.17 (REF)
unnamed: C2.1, IC4.17 (REF)
S0: IC1.10 (S0), IC2.10 (S0), X9.1
S1: IC1.11 (S1), IC2.11 (S1), X9.2
S2: IC1.14 (S2), IC2.14 (S2), X9.3
S3: IC1.13 (S3), IC2.13 (S3), X9.4
SCLK: IC3.21 (SCLK), IC4.21 (SCLK), X10.5
VCC: IC1.1 (COMMON_INPUT/OUTPUT), IC1.24 (VCC), IC2.1 (COMMON_INPUT/OUTPUT), IC2.24 (VCC), IC3.19 (VDD), IC4.19 (VDD), X9.7, X10.8

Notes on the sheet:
Aightech


Board: 2 copper layers, 100.0 x 100.0 mm, 81 parts (0 on the bottom side), 81 nets.

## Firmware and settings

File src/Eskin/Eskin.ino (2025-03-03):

#include "fsr.hpp"
#include "lis3dh.h"
#define ACC_SAMPLE_RATE 1000
#define FSR_SAMPLE_RATE 200

uint8_t arr0x17[16] = {0x1F, 0x23,             //21
                       0x22, 0x22,             //21
                       0x23, 0x23,             //25
                       0x1F, 0x1C,             //D
                       0x1E, 0x23, 0x23, 0x1C, //D
                       0x1F, 0x22, 0x1C, 0x1E};

FSR fsr;

uint16_t fsr_data[2 * 16 * 16];
int16_t acc_data[3 * 4 * 4];
uint32_t ts_acc = 0;
uint32_t ts_fsr = 0;
uint8_t size_acc = 16;
uint8_t size_fsr = 0;
uint8_t layers_fsr = 0;
int count = 0;

uint8_t LIS3DH::last_index = 0;

//protocol:
//read 1 byte: 2 MSB bits are mode, 6 LSB bits are size
//mode 0: request 1 FSR array of size*size elements
//mode 1: request 2 FSR array of size*size elements
//mode 2: request 1 ACC array of size*size elements
//mode 3: request 1 ACC array and 2 FSR arrays of size*size elements

//reply format:
//- 4 bytes: timestamp acc => if != 0, then the requested amount of data will be sent
//- 4 bytes: timestamp fsr => if != 0, then the requested amount of data will be sent
//- data requested if timestamps != 0

IntervalTimer timer_acc;
IntervalTimer timer_fsr;

LIS3DH lis3dh[16];

int aa = 1;

void
acc_callback()
{
    if(size_acc == 0)
        return;
    ts_acc = micros();

    for(int i = 0; i < 16; i++)
    {
        lis3dh[i].getAccelerationRaw(&acc_data[i * 3], &acc_data[i * 3 + 1],
                                     &acc_data[i * 3 + 2]);
        // Serial.print(acc_data[i * 3 + 2]);
        // Serial.print(" ");
    } //256us
    // Serial.println();
}

void
fsr_callback()
{
    if(size_fsr != 0 && layers_fsr != 0)
    {
        ts_fsr = micros();
        if(layers_fsr == 1)
            fsr.scan_array(fsr_data, size_fsr);
        else //1053us
            fsr.scan_2array(fsr_data, size_fsr);
        //[fsr_l1_row1, fsr_l2_row1, fsr_l1_row2, fsr_l2_row2, ...]
    }
}

void
setup()
{
    Serial.begin(115200);
    // // while(!Serial);
    fsr.begin();
    delay(1000);
    

    SPI1.begin();

    // initialize LIS3DH accelerometers
    for(int i = 0; i < 16; i++)
    { // pass select_address function to LIS3DH constructor
        lis3dh[i].begin(SPI1, i);
        lis3dh[i].setFullScaleRange(LIS3DH_RANGE_2G);
        lis3dh[i].setOutputDataRate(LIS3DH_DATARATE_5KHZ);
        lis3dh[i].setHighSolution(true);
        // lis3dh[i].openTemp();
        delay(1);
    }

    // timer_acc.begin(acc_callback, 1000000 / ACC_SAMPLE_RATE);
    //timer_fsr.begin(fsr_callback, 1000000 / FSR_SAMPLE_RATE);
}
 
void
loop()
{
    if(Serial.available() > 0)
    {
        uint8_t cmd = Serial.read(); //get the command
        uint8_t mode = cmd >> 6;     //extract the mode
        uint8_t size = cmd & 0x3F;   //extract the size

        switch(mode)
        {
        case 0:             //request 1 FSR array of size*size elements
            noInterrupts(); //disable interrupts to avoid data corruption with callbacks
            size_fsr = size; //set the size of the array to read
            layers_fsr = 1;  //set the number of layers to read
            size_acc = 0;    //reset the size of the acc array to not read it
            Serial.write(
                (uint8_t *)&ts_fsr,
                4); //send the timestamp of the last read (0 if no data available)
            if(ts_fsr != 0) //if data is available, send it
            {
                //the data is stored in fsr_data, and contains size*size elements of 2 bytes each
                Serial.write((uint8_t *)&fsr_data, 2 * size * size);
                ts_fsr =
                    0; //reset the timestamp to signal that the data has been read
            }
            interrupts();
            break;
        case 1: //request 2 FSR array of size*size elements
            noInterrupts();
            size_fsr = size;
            layers_fsr = 2;
            size_acc = 0;
            Serial.write((uint8_t *)&ts_fsr, 4);
            if(ts_fsr != 0)
            {
                Serial.write((uint8_t *)&fsr_data, 4 * size * size);
                ts_fsr = 0;
            }
            interrupts();
            break;
        case 2: //request 1 ACC array of size*size elements
            noInterrupts();
            size_acc = size;
            size_fsr = 0;
            Serial.write((uint8_t *)&ts_acc, 4);
            if(ts_acc != 0)
            {
                Serial.write((uint8_t *)&acc_data, 2 * size * size);
                ts_acc = 0;
            }
            interrupts();
            break;
        case 3: //request 1 ACC array of 4*4 elements and 2 FSR arrays of size*size elements
            //no parallelism, the data is sent in the order ACC, FSR1, FSR2
            ts_acc = micros();
            for(int i = 0; i < 16; i++) //256us
                lis3dh[i].getAccelerationRaw((uint8_t *)&acc_data[i * 3]);
            ts_fsr = micros();
            //[fsr_l1_row1, fsr_l2_row1, fsr_l1_row2, fsr_l2_row2, ...]
            fsr.scan_2array(fsr_data, size);
            Serial.write((uint8_t *)&ts_acc, 4);
            Serial.write((uint8_t *)&ts_fsr, 4);
            Serial.write((uint8_t *)&acc_data, 2 * 16 * 3);
            Serial.write((uint8_t *)&fsr_data, 2 * 2 * size * size);
            break;
        }
    }
}

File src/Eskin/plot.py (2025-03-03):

import sys
import time
import numpy as np
import serial
from PyQt5 import QtCore, QtWidgets
import pyqtgraph.opengl as gl

class SerialReader(QtCore.QThread):
    data_received = QtCore.pyqtSignal(np.ndarray, np.ndarray)
    
    def __init__(self, port, parent=None):
        super(SerialReader, self).__init__(parent)
        self.port = port
        self.running = True
        try:
            self.ser = serial.Serial(port, 500000, timeout=3)
            time.sleep(1)
            self.ser.reset_input_buffer()
            self.ser.reset_output_buffer()
        except Exception as e:
            print("Serial connection error:", e)
            self.running = False

    def run(self):
        mode = 0b11
        size = 16
        cmd = (mode << 6) | size
        cmd_bytes = cmd.to_bytes(1, 'big')
        data_len = 8 + 96 + 1024  # Total data length (in bytes)
        while self.running:
            try:
                self.ser.write(cmd_bytes)
                d = self.ser.read(data_len)
                if len(d) != data_len:
                    continue
                # dt values (unused here)
                _ = int.from_bytes(d[0:4], "little")
                _ = int.from_bytes(d[4:8], "little")
                # 16 accelerometer readings, each with 3 values (int16)
                acc = np.frombuffer(d[8:8 + 16*6], dtype=np.int16).reshape(16, 3)
                # FSR data: 16 readings, 2 layers, each with 16 values (uint16)
                fsr = np.frombuffer(d[8 + 16*6:], dtype=np.uint16).reshape(16, 2, 16)
                self.data_received.emit(acc, fsr)
            except Exception as e:
                print("Serial read error:", e)
                self.running = False

    def stop(self):
        self.running = False
        self.wait()
        if self.ser.is_open:
            self.ser.close()

class MainWindow(QtWidgets.QMainWindow):
    def __init__(self, serial_port, parent=None):
        super(MainWindow, self).__init__(parent)
        self.setWindowTitle("Real-time 3D Plot")
        self.widget = gl.GLViewWidget()
        self.setCentralWidget(self.widget)
        self.widget.opts['distance'] = 40
        
        # 1D arrays for FSR surfaces (required by GLSurfacePlotItem).
        self.xgrid = np.linspace(0, 15, 16)
        self.ygrid = np.linspace(0, 15, 16)
        
        # Create FSR surfaces for two layers (16x16 grid each).
        self.surface_fsr0 = gl.GLSurfacePlotItem(x=self.xgrid, y=self.ygrid, z=np.zeros((16, 16)),
                                                 shader='shaded', color=(1, 0, 0, 0.5))
        self.surface_fsr0.translate(-8, -8, 0)
        self.widget.addItem(self.surface_fsr0)
        
        self.surface_fsr1 = gl.GLSurfacePlotItem(x=self.xgrid, y=self.ygrid, z=np.zeros((16, 16)),
                                                 shader='shaded', color=(0, 1, 0, 0.5))
        self.surface_fsr1.translate(-8, -8, 0)
        self.widget.addItem(self.surface_fsr1)
        
        # Create a scatter plot for the accelerometer data (16 points).
        # Each dot's position (x, y, z) will represent its acceleration.
        self.scatter_acc = gl.GLScatterPlotItem(pos=np.zeros((16, 3)), size=10, color=(0, 0, 1, 1))
        self.widget.addItem(self.scatter_acc)
        
        # Start the serial reading thread.
        self.serial_thread = SerialReader(serial_port)
        self.serial_thread.data_received.connect(self.update_data)
        self.serial_thread.start()
        
    def update_data(self, acc, fsr):
        # Update FSR surfaces.
        # Assume fsr[:, 0, :] corresponds to layer 0 and fsr[:, 1, :] to layer 1.
        fsr0 = fsr[:, 0, :].astype(np.float32)/100.+4
        fsr1 = fsr[:, 1, :].astype(np.float32)/100.
        self.surface_fsr0.setData(z=fsr0)
        self.surface_fsr1.setData(z=fsr1)
        
        # Update the accelerometer scatter plot.
        # Use the accelerometer readings directly as (x, y, z) positions.
        acc_float = acc.astype(np.float32)/16384.

        lookupArr = [0, 7, 8, 9, 5,  6, 15, 10, 4, 2, 12, 11, 3, 1, 14, 13]
        acc_float = acc_float[lookupArr]
        # add grid offset to the x and y axis
        for ix in range(4):
            for iy in range(4):
                acc_float[ix*4+iy, 0] = acc_float[ix*4+iy, 0] + ix*4 -8
                acc_float[ix*4+iy, 1] = acc_float[ix*4+iy, 1] + iy*4 -8
                acc_float[ix*4+iy, 2] = acc_float[ix*4+iy, 2] + 6

        self.scatter_acc.setData(pos=acc_float)
        
    def closeEvent(self, event):
        self.serial_thread.stop()
        event.accept()

if __name__ == '__main__':
    if len(sys.argv) < 3:
        print("Usage:")
        print("\t{} arduino_port n_array".format(sys.argv[0]))
        print("Ex:")
        print("\t{} COM5 16".format(sys.argv[0]))
        sys.exit(1)
        
    app = QtWidgets.QApplication(sys.argv)
    window = MainWindow(sys.argv[1])
    window.show()
    sys.exit(app.exec_())

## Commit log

2022-07-01 added board
    [fsr_array.brd, fsr_array.sch]
2022-07-01 Solidwork model
    [Assem1.SLDASM, FSRarray_holder_small.SLDPRT, FSRarray_holder_small.STL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]
2022-08-29 added matlab script
    [CMakeConfig.txt]
2022-08-31 letters models
    [Assem1.SLDASM, Assem2.SLDASM, FSRarray_holder_small.SLDPRT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]
2022-09-14 update big letters
    [big_letters.SLDPRT, big_letters_c1.STL, big_letters_c2.STL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]
2022-09-14 update on letters
    [big_letters.SLDPRT, big_letters_c1.STL, big_letters_c2.STL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]
2022-10-25 v3 kicad
    [BOM-fsr_array.csv, BOM-inskinacc.csv, CMakeConfig.txt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]
2022-11-11 v2 pcbboard and comments on matlab script
    [CMakeConfig.txt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]
2023-05-25 working step for the cpp lsl publisher
    [BOM-KX134_array.csv, CMakeConfig.txt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]
2023-07-17 fixed minor bug + added ethernet teensy code
    [CMakeConfig.txt, FSRray.kicad_pcb, FSRray.kicad_sch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]
2023-08-14 updated LIS3DH array
    [CMakeConfig.txt, LIS3DH_array.kicad_pcb, LIS3DH_array.kicad_sch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]
2024-03-16 updated lis3dh array: fpc connectors
    [BOM-FSRray.csv, BOM-LIS3DH_array.csv, CMakeConfig.txt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]
2024-07-18 added LIS2DH version with or gate to solve SPI/i2C interaction
    [BOM-LIS2DH_array.csv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]
2024-07-20 working code for the accelerometers + FSRs
2024-08-31 added or gate on each acc to prevent I2C interference when the chip have CSB high
    [BOM-LIS3DH_array.csv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]
2024-09-01 updated lis2dh arrays
    [BOM-LIS2DH_array.csv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]
2024-09-29 new custom fsr model
    [customFSReay.kicad_pcb, customFSReay.kicad_sch]
2024-10-04 modify the fixation position to fit better on finger
    [BOM-customFSReay.csv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]
2024-10-21 added teeardrops
    [CMakeConfig.txt, customFSReay.kicad_pcb]
2025-02-27 starting tear drops
    [BOM-customSquare16x16mini.csv, CMakeConfig.txt, customSquare16x16.kicad_pcb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]

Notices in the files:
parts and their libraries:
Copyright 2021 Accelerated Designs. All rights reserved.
